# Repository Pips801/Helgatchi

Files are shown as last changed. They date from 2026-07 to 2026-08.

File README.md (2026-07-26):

# Helgatchi
Handheld BLE + WiFi Hunter

## What is it?
A portable, hand-held BLE beacon and WiFi AP scanner/hunter, with built-in alerting, 1.69” full-color screen, and external SMA-RP antenna all powered by the XIAO ESP32-S3. 

The Helgatchi will passively scan for BLE devices and WiFi SSIDs/APs, and alert when specific Manufacturers, naming schemes, or services are discovered. 

It can be configured to alert anything you want, such as:
- ALPR/Surveilance equipment
- Tactical equipment
- Cameras
- Hidden cameras
- Fitness wearables
- Audio/Video devices

You can create rules based on the following fields
| 🐑  	| MAC address 	| OUI (explicit) 	| OUI organization 	| MFG (explicit) 	| MFG organization 	| 802.11 SIG 	| Device name 	| SSID 	|
|---	|---	|---	|---	|---	|---	|---	|---	|---	|
| WiFi 	| ✅ 	| ✅ 	| ✅ 	| ❌ 	| ❌ 	| ✅ 	| ❌ 	| ✅  	|
| BLE  	| ✅ 	| ✅ 	| ✅ 	| ✅ 	| ✅ 	| ❌ 	| ✅ 	| ❌  	|

## Key Features
- Enclosed, portable, battery powered handheld rechargeable BLE and WiFi scanner and hunter that can live in your pocket.
- Passively scans for beacons in the background in-between sleeping - maximizing battery life. You can configure 
- Powered by the XIAO ESP32-S3
- 6 RGB LEDs
- 1.69" rounded screen
- Vibration motor for alerts
- You can change
  - Color scheme
  - Alert settings
    - Vibrate
    - LEDs
    - Screen Wake
  - Scan settings
    - Sleep duration
    - Scan duration
  - Rules for alerts
    - MAC address (BLE, WiFi)
    - Manufacturer (BLE, WiFi OUI)
    - Device name (BLE name, WiFi SSID)
    - Service (BLE)

## Specifications

| Spec | Info 	|
|---	|---	|
| MCU 	| XIAO ESP32-S3 	|
| Flash 	| 8MB 	|
| Battery  	| 400mAh - 1200mAh 3.7v LiPo 	|
| Screen 	| Waveshare 1.69” LCD - 240p × 280p 	|
| Antenna  	| XIAO -> u.FL > back PCB > SMA-RP > 2.4Ghz antenna 	|
| Size 	| Width: 50mm Length: 80mm 	|

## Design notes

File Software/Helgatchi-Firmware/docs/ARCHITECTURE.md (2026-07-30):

# Architecture

Quick map of the firmware. For per-phase implementation history see the
other docs in this directory; for current next-up work see `PHASE_6_SCAN_ENGINE.md`.

## Hardware

- **MCU**: ESP32-S3 (Seeed XIAO ESP32-S3 module)
- **Flash**: 8 MB
- **PSRAM**: 8 MB (LVGL framebuffers + LVGL allocator pool + scan ring + seen-devices map)
- **Display**: ST7789 SPI panel @ 80 MHz, 280×240 (no TE pin — frame tearing
  inherent above ~30 fps animation)
- **Radios**: BLE + WiFi (NimBLE for BLE, ESP32 WiFi for scan)
- **LEDs**: addressable WS2812 chain via FastLED
- **Motor**: PWM-driven haptic
- **Buttons**: left / right / center (debounced in `HalService`)
- **Battery**: VSENSE via ADC, USB-attach detect via SOF, charge-state inferred
- **Power**: deep-sleep wake via EXT1 on center button + RTC timer for scheduled scan windows; shipping mode for cold storage

## Build system

PlatformIO, Arduino-ESP32 framework. Three pre-scripts run before each
build (see `platformio.ini`):

1. `scripts/auto_montserrat.py` — scans source for referenced LVGL Montserrat
   font sizes and `-D`s them into the build.
2. `scripts/build_info.py` — emits `include/build_info.h` with build date and
   UI version (mtime of `Helgatchi UI.eez-project`).
3. `scripts/build_vendor_tables.py` — generates `include/vendor_tables_data.h`
   (~700 KB of flash data) from `scripts/vendor_sources/oui.csv.gz` and
   `scripts/vendor_sources/bt_companies.yaml`. Run
   `scripts/refresh_vendor_sources.py` manually to update the upstream cache.

Partition layout (`partitions.csv`): NVS 28 KB / factory 5 MB / spiffs ~3 MB
(LittleFS-formatted; partition subtype is `spiffs` because that's what
esptool/PIO look for, but the on-disk format is LittleFS via
`board_build.filesystem = littlefs`).

## Service model

Every subsystem is a `class FooService { void begin(EventBus&); void tick(); ... };`
with a single global instance (`extern FooService g_foo;`). `setup()` in
`main.cpp` initializes them in a specific order (some have prerequisites —
e.g. `g_rules` depends on `g_scan_service` and `g_alerts` being ready, and on LittleFS
being mounted).

Service catalog (`src/main.cpp` shows current init order):

| service | role |
|---|---|
| `g_bus` | Pub/sub event bus (queued; drained per main-loop tick) |
| `g_settings` | NVS-backed settings store (`SettingsKey` enum + `SKEY_*` macros) |
| `g_hal` | Display, LEDs, motor, buttons, ADC |
| `g_logger` | LVGL perf overlay gating, serial debug-level filtering |
| `g_console` | Serial command parser |
| `g_power` | Scan/sleep cycle, battery sampling, shipping mode |
| `g_alerts` | Active alert store (RTC slow memory persistence across deep sleep). Caps at 16 unacked — past that new detections are DROPPED, announced via `EV_ALERT_DROPPED` (throttled) so the UI can say so |
| `g_scan_service` | Scan-result ring buffer (256) + seen-devices map (128). Both in PSRAM |
| `g_rules` | Rules engine — loads `/rules/{factory,user}/*.json`, drains `g_scan_service`  |
| `g_leds` | LED pattern renderer (~30 fps), pattern name registry |
| `g_vibe` | Haptic step-machine, pattern name registry |
| `g_ui` | LVGL `lv_timer_handler` wrapper, render gating when screen off |
| `g_display` | Top-bar icon strings (battery / USB / BT / WiFi / bell) |
| `g_toast` | Transient self-dismissing messages on the LVGL top layer. No `begin()` — call `g_toast.show("…")` from any UI code |
| `g_settings_screen` | Settings widget wiring (EEZ-generated UI) |
| `g_alerts_screen` | Alert card UI (lives in its own file mirroring settings_service split)|

## Event bus

`include/event_ids.h` is the source of truth for event IDs. Two flavors:

- `CMD_*` — imperative requests (`CMD_SCAN_START`, `CMD_ALERT_ACK`, etc.)
- `EV_*` — immutable facts (`EV_ALERT_RAISED`, `EV_BATTERY_UPDATED`, etc.)

Payloads are an 8-byte tagged union (`include/event_payload.h`). Adding a new
event ID *to send a custom payload* means extending the union.

**Hot path note**: scan results do NOT go through the bus. `g_scan_service.publish()`
writes to a PSRAM ring buffer; `g_rules.tick()` drains it directly via
`g_scan_service.drain()`. Only the alert path that fires *after* matching emits bus
events (downstream of the hot loop).

## Storage tiers

| tier | what lives here |
|---|---|
| Flash (app) | Firmware, generated vendor tables, factory rule JSONs (via LittleFS image at build time) |
| NVS | Settings (`g_settings`), rule enable/disable overlay |
| RTC slow memory  | Active alerts (`g_alerts`) — survives deep sleep, cleared on cold boot |
| LittleFS | `/rules/factory/*.json` (read-only at runtime), `/rules/user/*.json` (writable) |
| PSRAM | LVGL framebuffers + LVGL allocator pool, scan ring + seen-devices map |
| Internal SRAM | Stack, FreeRTOS, hot in-flight data only |

## Conventions

- **Singular/plural serial verbs**: `setting`/`settings`, `alert`/`alerts`,
  `led`/`leds`, `rule`/`rules`. Singular mutates one thing; plural lists or
  manages many.
- **Underscore-as-space in serial values**: multi-word titles in `alert` and
  `rule create` use underscores (`title=Axon_device_nearby`). Other fields
  (vibe, led, type, action, etc.) take registry names verbatim.
- **Comma-separated arrays in rule criteria**: `rule add foo mfg=0x05D2,0x004C`
  adds two atomic criteria. `oui_org_contains` and `mfg_org_contains` expand
  at parse time into many atomic criteria by walking the vendor table.
- **Per-(rule, MAC) dedup**: alerts use identifier format
  `<rule_name>:<MAC_hex>` so re-firing on the same device updates last_seen
  rather than stacking new alerts.
- **Factory rule immutability**: `_rules[i].is_factory == true` blocks all
  content mutations. Only `enable`/`disable` works on factory rules, persisted
  via NVS overlay (survives FS reflash).

## Debugging / introspection commands

- `stats` — uptime, chip, memory, display fps, bus drops
- `scan` — list seen devices (dedup'd by MAC)
- `scan inject domain=... mac=... mfg=... name=...` — synthesize a scan
  result for testing the rules engine without real radio
- `vendor oui <AA:BB:CC>` / `vendor mfg <0xNNNN>` — forward lookup
- `vendor search <substr>` — list every IEEE org + BT SIG name containing the
  substring (same code path RulesService takes at rule load for `*_org_contains`)
- `rules` — list all rules with their full criteria (so `rule rm <name> <idx>`
  is unambiguous)
- `rules show <name>` / `rules stats` / `rules reload`
- `selftest` — GPIO short/load detection

## Things that have already burned us

- **DMA + PSRAM**: cache writeback needed before LovyanGFX flushes from PSRAM.
  See the `Cache_WriteBack_Addr` call in `ui_controller.cpp` flush_cb.
- **NimBLE timing**: not in the codebase yet (Phase 6), but historically
  `NimBLEDevice::init` on Arduino-ESP32 must come after WiFi init if both
  share radio coex.
- **LittleFS unlink while iterating**: the directory iterator holds FDs on
  entries — collect paths first, close the dir, then unlink.
- **Partition table changes** wipe NVS (and reformat LittleFS if the
  partition moves). Avoid changing offsets once stable.
- **ArduinoJson 7** allocates dynamically; on big rule files use stack-scoped
  `JsonDocument` to avoid leaks.

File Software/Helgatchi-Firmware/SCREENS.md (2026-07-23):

# Screens

This document describes the actual UI screens, their SquareLine Studio
implementation, and the wiring between SLS-exported widgets and firmware
behavior. The earlier revision was a design intent — this one tracks what
exists, what doesn't, and the conventions in use.

---

## Source of truth

- **SLS project** (external): `Helgatchi-UI`, SLS 1.6.0, targeting LVGL 9.3, "Arduino with TFT_eSPI" board template, "Force exported names to lower case" enabled, "Custom variable prefix" `uic`.
- **Exported files**: `src/UI/*.{c,h}` — *do not edit by hand, re-export overwrites.*
- **Firmware wiring**: `src/ui_controller.cpp`. All buttons / settings / battery / dim / haptic hooks live here.

Whenever the SLS project is re-exported, widget pointer names may change. The compiler will catch most of these as undeclared identifiers in `_bindings[]` / `_actions[]` / batteryLabels[] in `ui_controller.cpp`.

---

## Screens that exist today

| # | Screen | SLS object | Status |
|---|---|---|---|
| 1 | Splash | `ui_screen_splash_screen` | ✅ Implemented |
| 2 | Status | `ui_screen_status_screen` | ✅ Renders top bar, no body content yet |
| 3 | Menu | `ui_screen_menu_screen` | ✅ Horizontal carousel, only Settings panel exists |
| 4 | Settings | `ui_screen_settings_screen` | ✅ Most-developed screen — actual settings widgets bound to NVS |

Screens deferred to later milestones: **Scan, Devices, Device Detail, Rules, Alerts, About**. Each will follow the same pattern as Settings (top bar component + content panel + binding table).

---

## Top bar component

Built once in SLS as a Component, instanced on Status / Menu / Settings (purple in the Hierarchy panel — they share the same Component definition and update together if edited).

Three labels per instance, named consistently across screens:
- `top_bar_left_text` — left-side status indicator (currently shows "zzz" placeholder on Menu, free text per screen)
- `top_bar_center_text` — screen title
- `top_bar_right_text` — battery percentage

The right-text labels are tracked in `_batteryLabels[]` in `ui_controller.cpp`. On `EV_BATTERY_UPDATED` they all get rewritten with the formatted percentage / "CHRG" / "FULL" / "??". A cached `_last_batt_*` is also re-applied when a screen loads, so a freshly-loaded screen paints immediately instead of waiting up to 30 s for the next battery sample.

To add the top bar to a new screen: drop the Component instance in SLS → re-export → add the new screen's `top_bar_right_text_*` pointer to `_batteryLabels[]`.

---

## Splash → Status

The splash → status transition is **defined in SLS itself**, not in C:
- Trigger: `LV_EVENT_SCREEN_LOADED` on splash
- Action: `Change Screen` to Status with `FADE_OUT`, 500 ms, **3000 ms delay**

The C side just calls `ui_init()` (loads splash) and lets LVGL handle the rest. This is the canonical SLS pattern — when something can be a CLICKED-event-driven screen change, prefer doing it in SLS.

The 3 second delay needs `lv_tick_set_cb(_tick_cb)` to be registered (LVGL 9.x removed `LV_TICK_CUSTOM`, so without this the delay never elapses). `UIController::begin()` does this before `lv_display_create`.

---

## Menu screen

Horizontal scroll-snap carousel (`ui_menu_screen_container_container5`). Each child panel is one menu entry. Currently only `panel_settings_pannel` (sic — SLS-generated typo) exists, with `lv_image_settings_image`, label, and a `Clicked → Change Screen → Settings` event defined in SLS.

Keypad navigation: `_grp_menu` is populated by iterating the carousel container's children, so adding a new menu panel in SLS (Devices, Rules, Alerts, etc.) auto-shows up in the focus cycle without code changes. LVGL's group focus auto-scrolls the snap container.

Adding a new menu entry:
1. In SLS: copy the Settings panel inside `container_container5`, rename, give it its own `Clicked → Change Screen → <target>` event
2. Re-export
3. (No C change needed for the menu screen itself)
4. Build / register the target screen separately

---

## Settings screen

The most-developed screen — every other future screen will follow this pattern.

### Layout
A top bar + a vertical scrollable panel (`panel_panel2`) of section labels and option containers. Each option container has a label and one widget (switch/dropdown/slider/button).

### Bound settings (`_bindings[]` in `ui_controller.cpp`)

Each entry is `{ &ui_<widget>, SKEY_<X> }` — the polymorphic `_readWidget` / `_writeWidget` handles the widget type at runtime, so a switch, dropdown, slider, etc. all work via the same path.

Currently bound:
| Widget | SLS pointer | SettingsKey |
|---|---|---|
| Brightness dropdown | `ui_settings_screen_dropdown_brightness` | `SKEY_SCREEN_BRIGHTNESS` |
| Performance Mode dropdown | `ui_settings_screen_dropdown_performance_mode` | `SKEY_PERF_MODE` |
| Debug over Serial switch | `ui_settings_screen_switch_debug_over_serial` | `SKEY_DEBUG_SERIAL_ENABLED` |
| Debug Level dropdown | `ui_settings_screen_dropdown_debug_level` | `SKEY_DEBUG_LEVEL` |
| Sleep with Serial switch | `ui_settings_screen_switch_sleep_while_serial` | `SKEY_DEBUG_SLEEP_WITH_SERIAL` |
| Sleep with USB switch | `ui_settings_screen_switch_sleep_while_usb` | `SKEY_SLEEP_WHILE_USB` |

### Custom (non-1:1) bindings

Some widgets don't map directly to a single SKEY:
- **BLE / WiFi scanning switches** combine into `SKEY_SCAN_MODE` via bit-OR (BLE = bit 0, WiFi = bit 1). Custom `_onScanBitsChanged` rebuilds the combined value from both switch states on any change. `_refreshScanBits()` in the other direction.
- **Show debug options switch** (`show_debug_options_switch`, `SKEY_DEBUG_ENABLED`): gates the visibility of the debug rows (`debug_over_serial_container`, `debug_level_container`, `device_info_container`, `reset_device_container`, `restart_tutorial_container`) via `_applyDebugVisibility()`. Default off; switching OFF also resets the [DEBUG] keys to defaults (cascade in SettingsService), and the factory reset re-hides everything. Keypad nav skips the hidden rows automatically (lv_group ignores objects with a hidden ancestor).

### Action buttons

Sleep and reboot moved to the power menu screen (which also owns the sleep
countdown text via `EV_SLEEP_COUNTDOWN_UPDATED`). The remaining settings-screen
buttons live in the debug section:
| Button | Behavior |
|---|---|
| `reset_device_button` | C-wired: `g_power_menu_screen.beginAction(CMD_POWER_FACTORY_RESET)` — shows the Power Action screen ("Wiping device...", cancellable during the hold), then factory wipe (settings/rules/alerts/admin) + reboot; comes back up like a first boot. The wipe+shipping-sleep variant `CMD_POWER_SHIPPING_RESET` is serial-only (`power shipping`) for the assembly line. |
| `debug_screen_button` | EEZ-flow navigation to the Debug Info screen |
| `restart_tutorial_button` | EEZ-flow navigation to the tutorial |

### Dropdown options must match the enum
SLS stores dropdown options as a `\n`-separated string and saves the index. **The index is the value stored in NVS.** If your dropdown options aren't in enum order, you'll silently store wrong values — we've eaten this bug twice (extra "Off" leading the Debug Level dropdown, slider range 50..255 vs enum 0..3 for brightness).

Current required option strings:
- Brightness: `Min\nLow\nMedium\nHigh\nMax` (matches `ScreenBrightness` enum)
- Performance Mode: `Performance\nBalanced\nPower Saver` (matches `PerfMode` enum, missing DYNAMIC by intent)
- Debug Level: `Info\nHigh\nRender\nScan\nPerf\nTeleplot` (index = `DebugLevel` enum value, 1:1). Perf = human-readable telemetry, Teleplot = `>k:v` graphing stream.

---

## Keypad input contract

UIController converts physical button events into LVGL keys with these conventions:

| Action | Default (nav mode) | In edit mode | Dropdown open |
|---|---|---|---|
| LEFT | `LV_KEY_PREV` (prev focused widget) | `LV_KEY_LEFT` (decrement value) | `LV_KEY_UP` (prev option) |
| RIGHT | `LV_KEY_NEXT` (next focused widget) | `LV_KEY_RIGHT` (increment value) | `LV_KEY_DOWN` (next option) |
| CENTER short on Status | open Menu (direct screen change, bypasses LVGL) | — | — |
| CENTER short elsewhere | `LV_KEY_ENTER` | `LV_KEY_ENTER` (commit edit) | `LV_KEY_ENTER` (select option) |
| CENTER long | back to Status (panic-out) | — | — |

**Common mistakes**:
- Sending `LV_KEY_LEFT/RIGHT` for navigation. Switches interpret those as direct toggle and you'll never get past the first switch in the focus group.
- Forgetting that `lv_dropdown_is_open()` is widget-local state, not group editing state. `lv_group_get_editing()` returns false even with a dropdown list visible. Both checks needed.

### Group population
`_populateGroupFromSubtree()` recursively walks a screen's widget tree and adds anything `lv_obj_check_type` recognises as interactive (switch, checkbox, dropdown, roller, slider, arc, button) to the group **in DOM order**. So the focus cycle matches the order children appear in SLS's Hierarchy panel — drag widgets there to reorder navigation.

---

## Screen lifecycle hooks

`_scr_evt_cb` (registered for all four screens via `_registerScreenLogging`) handles three things on every screen transition:

1. **Logging** — `[t] SCREEN_LOAD_START / LOADED / UNLOAD_START / UNLOADED  <name>` to serial when debug serial is on.
2. **Group switching** — on `LV_EVENT_SCREEN_LOAD_START`, set the keypad indev's group to the screen's group (or NULL for splash/status).
3. **Settings refresh** — on Settings screen load, repaint widget values from `g_settings`.

Plus battery label re-paint (`_refreshBatteryLabels`) on every screen-load so the right-text shows the latest reading immediately.

---

## What's not implemented

- **Scan screen** — needs to surface scan state, lock-on, scan mode toggle. Future commands: `CMD_SCAN_START`, `CMD_SCAN_STOP`, `CMD_SCAN_LOCKON_START/STOP`. Will subscribe to `EV_SCAN_STATE_CHANGED` for the toggle status.
- **Devices screen** — paged list. Needs Entity Store + AppState before this is meaningful. Pagination + per-row rendering will be the main UI work.
- **Device Detail screen** — view one entity, optionally `CMD_RULE_ADD_CUSTOM` from it.
- **Rules screen** — toggle rule packs (`CMD_RULE_PACK_ENABLE/DISABLE`), wipe customs.
- **Alerts screen** — list active + history, ack (`CMD_ALERT_ACK`) / snooze (`CMD_ALERT_SNOOZE`).
- **About screen** — firmware version, build info, ruleset version.

The pattern for each is identical to Settings: SLS top-bar instance + content layout + add the appropriate widgets to either `_bindings[]` (state) or `_actions[]` (commands). Screen-load hook for any data that needs paint-on-entry.

---

## Cross-cutting

### `EV_UI_ACTIVITY` is used as the activity heartbeat
Every button press posts it. Every character typed in the serial console posts it. PowerManager updates `_last_activity_ms` and forces display ON. If a future input source (touch, gesture) is added, fire `EV_UI_ACTIVITY` from there too.

### Render is gated by display state
`UIController::tick()` is a no-op when `_render_enabled` is false. PowerManager flips it from `_setDisplay`: `OFF → false`, `ON/DIM → true`. This saves ~70 % CPU during silent TIMER-wake scan windows.

### LVGL FPS overlay
Compiled in via `LV_USE_PERF_MONITOR=1`, but visibility is runtime-toggled by `LogService::applyPerfMonitor()` based on `DebugLevel`. Reapplied on:
- After `g_ui.begin()` (display-create auto-shows the overlay; we have to actively re-hide if level < PERF)
- On every `EV_SETTINGS_CHANGED` that crosses the PERF threshold
- On `_setDisplay(ON/DIM)` (covers wake-from-silent-scan transitions)

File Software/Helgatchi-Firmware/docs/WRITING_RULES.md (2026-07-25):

# Writing rulesets

The authoritative guide to Helgatchi's rules engine: how rulesets and rules
work, every field, the pattern/regex language, worked examples, how to get a
ruleset onto the device, and how to test it. If you're creating or editing a
ruleset, this is the page to read.

**Terminology.** A **ruleset** is a single JSON file. It holds a collection of
**rules** plus the alert behaviour (title, LED, vibration, type, …) to use when
the ruleset fires. Each **rule** is one match entry — an object in the file's
`criteria` array. A ruleset fires when **any** of its rules matches a nearby
device; it then raises a single alert configured by that ruleset. Because
behaviour is per-ruleset, **don't duplicate the same rule across multiple
rulesets** — a device that matches two rulesets raises two alerts.

## Contents

1. [Quick reference](#1-quick-reference)
2. [How rulesets & rules work](#2-how-rulesets--rules-work)
3. [Ruleset anatomy — the top-level fields](#3-ruleset-anatomy--the-top-level-fields)
4. [Rules — the match entries](#4-rules--the-match-entries)
5. [Patterns & regex](#5-patterns--regex)
6. [Vendor-name matching](#6-vendor-name-matching)
7. [Worked examples](#7-worked-examples)
8. [A full annotated ruleset](#8-a-full-annotated-ruleset)
9. [Deploying rulesets](#9-deploying-rulesets)
10. [Console command reference](#10-console-command-reference)
11. [Testing & validating your ruleset](#11-testing--validating-your-ruleset)
12. [Migration note](#12-migration-note)
13. [Gotchas checklist](#13-gotchas-checklist)
14. [Internals (for engine contributors)](#14-internals-for-engine-contributors)

---

## 1. Quick reference

A ruleset is one JSON file. Minimal shape:

```json
{
  "name": "flock_safety",
  "title": "Flock nearby",
  "type": "ble",
  "criteria": [
    { "oui": ["B4:1E:52"] },
    { "name": [".*flock.*", ".*alpr.*"] }
  ]
}
```

**Ruleset fields** (top level)

| Field | Required | Value |
|---|---|---|
| `name` | yes | unique id, ≤ 55 chars. For **user** rulesets it is also the on-disk filename (`/rules/user/<name>.json`), so keep it path-safe — `[a-z0-9_]`. Factory rulesets are read-only (never written back) and may use display-style names, including spaces (e.g. `"Flock Safety"`). |
| `title` | no  | text on the alert card (defaults to `name`) |
| `type` | no  | `ble` \| `wifi` \| `sys` \| `batt` \| `auto` (default: infer) |
| `action` | no  | `alert` (default) \| `party` |
| `vibe` | no  | haptic pattern name (`vibe list` on the console) |
| `led` | no  | LED pattern name (`led list` on the console) |
| `tag` | yes | array of category tags (e.g. `["tactical", "camera"]`) |
| `criteria` | yes | the ruleset's rules — an array of match entries (below) |

**Rule fields** (each entry in `criteria`)

| Field | Matches | Value |
|---|---|---|
| `oui` | leading MAC bytes (24–48 bit) | `"B4:1E:52"`, `"70:B3:D5:1A:2"` |
| `mac` | full 6-byte MAC | `"12:34:56:78:9A:BC"` |
| `mfg` | BT SIG company id | `"0x05D2"` |
| `service` | advertised BLE service UUID | `"180F"`, `"0x180F"`, or full 128-bit |
| `name` | BLE name / Wi-Fi SSID | **pattern** |
| `ssid` | name, Wi-Fi only | **pattern** |
| `oui_org` | IEEE vendor name for the OUI | **pattern** (matched at runtime) |
| `mfg_org` | BT SIG company name | **pattern** (matched at runtime) |
| `ie_sig`  | Wi-Fi 802.11 IE fingerprint, Wi-Fi only | **pattern** (see below) |

`ie_sig` matches the ordered information-element fingerprint the WiFi sniffer
builds for each captured beacon / probe request: the IE tag numbers in order,
SSID (tag 0) omitted, joined by `;`, with vendor IEs (tag 221) expanded to
`221:<first up-to-8 payload bytes in lowercase hex>`. Example (a Flock camera's
station-mode probe request):
`2;12;127;221:506f9a16030103;45;191;221:0050f208000000`. Use `;` — not `,` —
between tags (comma is the criterion value separator). This fingerprint identifies
a device by *how* it probes, independent of its (often shared or randomized) MAC —
it's how the Flock ruleset tells a real camera from any other Espressif/Liteon
device. To capture one from a real device, enable WiFi scanning and read the `ie=`
field off the `scan` debug log (`debug level scan`).

**Pattern cheat sheet** (case-insensitive, matches the *whole* value)

| Intent | Pattern |
|---|---|
| equals | `flock` |
| contains | `.*flock.*` |
| starts with | `flock.*` |
| ends with | `.*cam` |
| regex | `BWL\d-\d*` (in JSON: `"BWL\\d-\\d*"`) |

---

## 2. How rulesets & rules work

The scan engine publishes every BLE/Wi-Fi sighting into a ring buffer. The rules
service drains that ring and tests each sighting against the rules of every
**enabled** ruleset. When any rule in a ruleset matches, the ruleset fires its
action (raise an alert, or start party mode) using its configured behaviour.

Rulesets load **disabled** — shipped factory rulesets and anything flashed later
arrive silent until the user enables them (rules screen, `rule enable <name>`,
or the upcoming tag bulk-toggles). The exception: rulesets deliberately created
on-device (`rule create` / `rule save`) start enabled. Enabled-state lives in an
NVS overlay, not in the ruleset files, so it survives an FS reflash; a factory
reset or full erase returns every ruleset to disabled.

- **Behaviour is per-ruleset.** `title`, `led`, `vibe`, `type` and `action` are
  set once on the ruleset and apply to whatever its rules match.
- **Within a ruleset, everything is OR.** Any one rule matching fires the
  ruleset, and any one value inside a rule counts as a hit. There is **no AND**
  across the rules of a ruleset today — every rule is OR'd.
- **Don't duplicate a rule across rulesets.** Each ruleset that matches a device
  fires independently, so overlapping match logic in two rulesets means two
  alerts for the same device. Put a given match in exactly one ruleset.
- **One fire per (ruleset, sighting).** Matching stops at the first rule that
  hits in a ruleset.
- **Dedup is per (ruleset, MAC).** A device that keeps advertising refreshes the
  ruleset's existing alert ("last seen") instead of stacking duplicates.
- **`type` categorises the alert; it does not gate matching.** A `name` rule is
  tested against both BLE names and Wi-Fi SSIDs. Only `ssid` is Wi-Fi-gated.
- **Factory beats user.** On a `name` collision the read-only factory ruleset
  wins.
- **Enable/disable is sticky.** Disabling a ruleset is stored in NVS and survives
  a reboot and even a filesystem reflash.

---

## 3. Ruleset anatomy — the top-level fields

These configure the ruleset's identity and the alert it raises.

### `name` (required)

The unique id and the filename (`<name>.json`). Lowercase letters, digits and
underscores only; ≤ 55 characters. Cannot be changed after creation via the
editor (it's the identity).

### `title`

The human string shown on the alert card. Defaults to `name`. May contain
spaces and punctuation. (Over the serial console an underscore becomes a
space — see §10.)

### `type`

The alert category, one of:

| Value | Meaning |
|---|---|
| `ble`  | Bluetooth device |
| `wifi` | Wi-Fi device |
| `sys`  | system alert |
| `batt` | battery alert |
| `auto` | infer from the sighting's radio (default if omitted) |

This only labels the resulting alert; it does **not** restrict which sightings
the ruleset can match.

### `action`

- `alert` (default) — raise/refresh an alert card with the ruleset's `title`,
  `vibe` and `led`.
- `party` — trigger party mode (rainbow LEDs, haptics, animation); no alert
  card. Used by `party.json`.

### `vibe` / `led`

Names of registered haptic / LED patterns. Omit for the service default. List
the available names on the console with `vibe list` and `led list`.

---

## 4. Rules — the match entries

`criteria` is the ruleset's list of rules. Each rule is a single-key object that
names one field and gives an array of values (the values within a rule are OR'd).
There are two kinds of field.

### Literal fields

| Field | Format | Notes |
|---|---|---|
| `oui` | `"B4:1E:52"`, `"8C:1F:64:F"`, `"70:B3:D5:1A:2"` | a leading MAC prefix, 24–48 bits: MA-L (3 octets), MA-M (28-bit / 7 nibbles), MA-S (36-bit / 9 nibbles), up to a full MAC. Colons optional; an odd trailing nibble is allowed. Use `mac` for an exact address. |
| `mac` | `"12:34:56:78:9A:BC"` | a single exact device |
| `mfg` | `"0x05D2"` | 16-bit BT SIG company id from the advert |
| `service` | `"180F"` / `"0x180F"` / `"0000180f-0000-1000-8000-00805f9b34fb"` | a service UUID advertised by the device; short forms are promoted onto the BLE base UUID |

### Pattern fields

| Field | Matched against | When |
|---|---|---|
| `name` | BLE adv name or Wi-Fi SSID | runtime, per sighting |
| `ssid` | the name, **only for Wi-Fi** sightings | runtime |
| `oui_org` | the IEEE vendor name of the sighting's OUI | resolved per sighting |
| `mfg_org` | the BT SIG company name of the mfg id | resolved per sighting |

`oui_org` / `mfg_org` resolve the sighting's vendor name at match time (one
cached vendor lookup per sighting) and test the pattern against it — there's no
vendor-table scan at load, so they don't slow boot. See §6.

---

## 5. Patterns & regex

### The key principle

> A pattern is **case-insensitive** and must match the **whole** value.

Full-match (anchored) is the thing people trip on: `flock` means the value *is
exactly* `flock`, not "contains flock". To match part of a value, add `.*`
wildcards yourself.

### The four everyday shapes

| Intent | Pattern | Matches | Does **not** match |
|---|---|---|---|
| equals | `flock` | `flock`, `FLOCK` | `flock-cam`, `myflock` |
| contains | `.*flock.*` | `Flock-Cam`, `myFLOCKing` | `flo`, `lock` |
| starts with | `flock.*` | `flock`, `flock-cam` | `myflock` |
| ends with | `.*cam` | `body-cam`, `CAM` | `camera` |

These cost nothing at runtime (they run as plain string compares — §14). Reach
for real regex only when a value has *structure* (a serial number, a suffix).

### Regex tokens

Patterns below are shown **as the matcher sees them**. In a JSON file every
backslash is doubled — `\d` is written `"\\d"` (see [JSON escaping](#writing-patterns-in-json)).

**`.` — any single character**

| Pattern | Matches | Not |
|---|---|-----|
| `a.c` | `abc`, `a5c`, `a-c` | `ac`, `abbc` |

**`* + ?` — repeat the preceding element** (zero-or-more, one-or-more, zero-or-one)

| Pattern | Matches | Not |
|---|---|-----|
| `ab*c` | `ac`, `abc`, `abbbc` | `abx` |
| `ab+c` | `abc`, `abbc` | `ac` |
| `colou?r` | `color`, `colour` | `colouur` |

**`\d \D` — digit / non-digit**

| Pattern  | Matches | Not |
|---|---|-----|
| `\d\d\d` | `192`, `007` | `19`, `1a2` |
| `cam\d+` | `cam1`, `cam42` | `cam`, `camx` |
| `\D` | `x`, `-` | `5` |

**`\w \W` — word `[A-Za-z0-9_]` / non-word**

| Pattern | Matches | Not |
|---|---|-----|
| `\w+` | `node_7`, `AB12` | `a-b`, `a b` |

**`\s \S` — whitespace / non-whitespace**

| Pattern | Matches | Not |
|---|---|-----|
| `ap\sname` | `ap name` | `apname` |

**`[...]` `[^...]` — character sets & ranges** (ranges fold case: `[a-z]` also matches `B`)

| Pattern | Matches | Not |
|---|---|-----|
| `[bc]at` | `bat`, `cat` | `hat` |
| `[0-9a-f]+` | `3f`, `a0b1` | `3g`, `xyz` |
| `[^_]+` | `abc` | `a_b` |

**`\` — escape a metacharacter to a literal** (`. * + ? [ ] ( ) { } | ^ $ \`)

| Pattern | Matches | Not |
|---|---|-----|
| `v\d\.\d` | `v3.1` | `v3x1`, `v31` |
| `10\.0\.0\.\d+` | `10.0.0.5` | `10x0x0x5` |
| `\*` | `*` | `x` |

**`^` `$` — anchors** — redundant (patterns are already fully anchored) but
tolerated. `^flock$` behaves exactly like `flock`.

### What's not supported (and what to do instead)

| Missing | Instead |
|---|---|
| alternation `a\|b` | use separate array values: `["a", "b"]` |
| bounded repeat `\d{2,4}` | spell it: `\d\d`, `\d\d\d?\d?`, or loosen to `\d+` |
| capture groups `(ab)+` | flatten the pattern |
| backreferences | not available |

Use **arrays** rather than clever single patterns — a single `name` rule can
carry several alternatives:

```json
{ "name": [".*flock.*", ".*alpr.*", "cam\\d+"] }
```

matches a name containing "flock", **or** "alpr", **or** the regex `cam\d+`.

### Writing patterns in JSON

JSON uses `\` for its own escapes, so a regex backslash must be **doubled**:

| Matcher sees | JSON file |
|---|---|
| `\d` | `"\\d"` |
| `\w+` | `"\\w+"` |
| `BWL\d-\d*`  | `"BWL\\d-\\d*"` |
| `v\.\d` | `"v\\.\\d"` |

A single `\d` in a file is invalid JSON — the whole file is rejected at load
with a parse error on the console. (The console `rule add` command is *not* JSON;
there you type a single backslash.)

### Limits

Patterns are capped at **64 characters**.

---

## 6. Vendor-name matching

`oui_org` and `mfg_org` match a **pattern against the vendor/company name** — so
you can flag a manufacturer without hand-listing their prefixes. At match time
the device's vendor name is looked up (from its OUI, or its BT SIG company id)
and your pattern is tested against it.

```json
{ "oui_org": [".*flock.*"] }       // fires when the OUI's IEEE vendor name contains "flock"
{ "mfg_org": [".*motorola.*"] }    // fires when the BT SIG company name contains "motorola"
{ "oui_org": ["sierra wireless"] } // exact vendor-name match (names are suffix-stripped)
```

Keep patterns reasonably specific — an overly broad one (`.*a.*`) will match a
huge range of vendors. Vendor names have corporate suffixes stripped
("Apple, Inc." → "Apple"), so match on the brand.

---

## 7. Worked examples

Each block below is a single rule you drop into a ruleset's `criteria` array.

**Regional serial scheme** (the WatchGuard case) — `BWL9-089912`, `BWL5-012241`:

```json
{ "name": ["BWL\\d-\\d*"] }
```

**Body cam labelled `AX` + exactly six digits** (no `{6}`, so spell it):

```json
{ "name": ["AX\\d\\d\\d\\d\\d\\d"] }
```

**Printer with a random hex suffix**, e.g. `HP-3f9a`:

```json
{ "name": ["hp-[0-9a-f]+"] }
```

**Access point on the 5 GHz band** whose SSID ends `_5G`:

```json
{ "ssid": [".*_5g"] }
```

**A device family by several keywords** (contains-any):

```json
{ "name": [".*dashcam.*", ".*bodycam.*", ".*evidence.*"] }
```

**A whole vendor, by name, without listing OUIs:**

```json
{ "oui_org": [".*axon.*"], "mfg_org": [".*axon.*"] }
```

**One exact device (allowlist/party target):**

```json
{ "mac": ["12:34:56:78:9A:BC"] }
```

**A longer OUI block** — an MA-M (28-bit) or MA-S (36-bit) assignment, more
specific than the shared 24-bit prefix it sits under:

```json
{ "oui": ["70:B3:D5:1A:2"] }
```

---

## 8. A full annotated ruleset

JSON has **no comments** — this block is annotated for learning only. A valid,
copy-pasteable version follows.

```jsonc
{
  "name": "acme_surveillance",   // ruleset id — [a-z0-9_], <= 55 chars, unique
  "title": "ACME gear nearby",   // text shown on the alert card
  "vibe": "double_tap",          // haptic pattern (omit for the default; `vibe list`)
  "led": "red_blue",             // LED pattern (omit for the default; `led list`)
  "type": "ble",                 // alert category: ble | wifi | sys | batt | auto
  "action": "alert",             // alert | party
  "criteria": [                  // the ruleset's rules — ANY one matching fires it (all OR'd)

    // --- literal rules ---
    { "oui": ["00:1D:96", "B4:1E:52"] },          // match either 24-bit MAC prefix
    { "mac": ["12:34:56:78:9A:BC"] },             // one exact device
    { "mfg": ["0x05D2", "0x0008"] },              // BT SIG company id(s)
    { "service": ["180F", "0x180A",               // advertised service UUID: short...
                  "0000fe2c-0000-1000-8000-00805f9b34fb"] }, // ...or full 128-bit

    // --- pattern rules (case-insensitive, whole-value) ---
    { "name": ["ACME.*",                          // name/SSID starts with "acme"
               ".*bodycam.*",                     // ...or contains "bodycam"
               "AX\\d\\d\\d\\d\\d\\d"] },          // ...or "AX" + exactly six digits
    { "ssid": [".*_5g", "ACME-[0-9]+"] },         // Wi-Fi ONLY: ends "_5g", or "ACME-"+digits
    { "oui_org": [".*acme.*"] },                  // any OUI whose vendor name contains acme
    { "mfg_org": [".*acme.*"] }                   // any BT SIG company containing acme
  ]
}
```

The same ruleset as a valid file (comments removed, backslashes doubled):

```json
{
  "name": "acme_surveillance",
  "title": "ACME gear nearby",
  "vibe": "double_tap",
  "led": "red_blue",
  "type": "ble",
  "action": "alert",
  "criteria": [
    { "oui": ["00:1D:96", "B4:1E:52"] },
    { "mac": ["12:34:56:78:9A:BC"] },
    { "mfg": ["0x05D2", "0x0008"] },
    { "service": ["180F", "0x180A", "0000fe2c-0000-1000-8000-00805f9b34fb"] },
    { "name": ["ACME.*", ".*bodycam.*", "AX\\d\\d\\d\\d\\d\\d"] },
    { "ssid": [".*_5g", "ACME-[0-9]+"] },
    { "oui_org": [".*acme.*"] },
    { "mfg_org": [".*acme.*"] }
  ]
}
```

---

## 9. Deploying rulesets

There are two homes for rulesets, with different install paths.

### Factory rulesets (shipped in the image)

Read-only seeds under `data/rules/factory/`. To add or change one:

1. Create/edit the `.json` file in `data/rules/factory/`.
2. Syntax-check it before flashing: `python -m json.tool data/rules/factory/your_ruleset.json`
   (prints the file if valid, or points at the first syntax error). Full
   behavioural testing comes after flashing — see §11.
3. Build and flash the filesystem image:
   ```
   pio run -t buildfs      # build the LittleFS image from data/
   pio run -t uploadfs     # flash it
   ```

Factory rulesets can't be edited on-device; the firmware never rewrites them.

### User rulesets (created at runtime)

Writable, stored under `/rules/user/`, auto-persisted on every change and kept
across a firmware-only reflash. Create them either way:

- **WebFlasher** — connect, open the rules card, add a ruleset with the field +
  match-mode dropdowns, Save. It sends `rule save <json>` for you.
- **Serial console** — `rule save <json>` for a whole ruleset, or build one up
  with `rule create <name>` then `rule add <name> <field>=<values>` (§10).

A user ruleset with the same `name` as a factory ruleset is ignored (factory
wins).

### Lifecycle

- `rule reload` — wipe in-memory rulesets and re-read both directories (also
  zeroes match counters).
- `rule enable <name>` / `rule disable <name>` — sticky, stored in NVS.
- `rule delete <name>` — removes a **user** ruleset and its file.
- `pio run -t erase` — nuke everything (NVS + filesystem). Only needed to escape
  stale state; not part of normal ruleset work.

---

## 10. Console command reference

The `rule` commands manage **rulesets** (the command name predates the
ruleset/rule split); `rule add` and `rule rm` add and remove individual rules
inside a ruleset.

```
rule                          show this help
rule list                     list every ruleset with its rules
rule show <name>              ruleset details + live match count
rule create <name> [k=v ...]  new user ruleset (k=v: title= vibe= led= type= action=)
rule add <name> <f>=<v>[,<v>] add one or more rules to a ruleset (space-separated)
rule rm <name> <idx>          remove the Nth rule from a ruleset
rule delete <name>            delete a user ruleset
rule enable  <name>           enable  a ruleset (NVS overlay)
rule disable <name>           disable a ruleset (NVS overlay)
rule reload                   re-read /rules/{factory,user}; zero counters
rule stats                    match / ring-drain counters
rule dump                     all rulesets as one JSON line (used by the WebFlasher)
rule save <json>              create/replace a user ruleset from a JSON object
```

Support commands:

```
led list                      list LED pattern names for `led`
vibe list                     list haptic pattern names for `vibe`
scan inject <k=v>             push a synthetic sighting (test the match path)
scan list                     show the seen-devices map
scan clear                    wipe the seen map
```

**Console input rules** (they differ from JSON):

- `_` becomes a space in string values, so `rule add r oui_org=sierra_wireless`
  matches "Sierra Wireless". A literal underscore can't be typed — use `\w` or
  author via JSON.
- No spaces or commas *inside* a value (they separate tokens / values).
- Backslashes are single here (`name=BWL\d-\d*`), doubled in JSON files.

Example, building a ruleset by hand:

```
rule create bwl_cams type=ble title=BWL_camera
rule add   bwl_cams name=BWL\d-\d*
rule add   bwl_cams oui_org=watchguard
rule show  bwl_cams
```

---

## 11. Testing & validating your ruleset

You don't need the real target device present to test a ruleset. The console can
inject synthetic sightings and report whether the ruleset fired. Run these in the
serial console or the WebFlasher's console view.

The goal is two checks: your ruleset **loads clean**, and it **fires on what you
intend — and nothing else**.

### Step 1 — Confirm it loaded

- **Saved via WebFlasher / `rule save`:** a bad ruleset is rejected on the spot
  (the editor shows an error; `rule save` prints `{"ok":false}`). Fix and resave.
- **Flashed as a factory file:** watch the boot log. You want
  `[rules] loaded N rules` (that count is rulesets). A malformed file logs a
  parse error naming the file; an unknown/removed field logs `bad criterion
  field`. Fix and reflash.
- Either way, run `rule show <name>` and read its rules back. Patterns print as
  `name ~ "..."`. **If a rule you wrote is missing, it was rejected** — usually
  an invalid pattern or a typo'd field name.

### Step 2 — Zero the counters

```
rule reload
```

This re-reads both directories and resets every ruleset's match counter to 0, so
you can measure from a clean slate. `rule show <name>` now reports `matches: 0`.

### Step 3 — Inject a device that SHOULD match

`scan inject` pushes a fake sighting through the real engine:

```
scan inject domain=bt mac=B4:1E:52:00:00:01 name=Flock-Cam
rule show flock_safety        # expect: matches: 1
```

Two constraints on injected sightings: the `name=` value **cannot contain
spaces**, and avoid `mac=AA:BB:CC:DD:EE:FF` (it triggers the factory party
ruleset). Set the fields your rules key on — `mac`/`oui` via `mac=`, `mfg` via
`mfg=`, `name`/`ssid` via `name=`, and `oui_org`/`mfg_org` by injecting a MAC
whose vendor your pattern matches.

### Step 4 — Inject a device that should NOT match

Just as important: prove the ruleset isn't too broad.

```
scan inject domain=bt mac=12:34:56:78:9A:B0 name=unrelated
rule show flock_safety        # expect: matches: 1  (unchanged)
```

This is where anchoring bugs show up. If you wrote `flock` (equals) but expected
"contains", a name like `Flock-Cam` won't match; if you wrote `.*a.*` you'll see
it match nearly everything.

### Step 5 — See the alert fire (optional)

`scan inject` a matching device, then check the device's alert screen (or the
`alerts` console command) for a card with your `title`, `vibe` and `led`.

### Step 6 — Clean up

```
rule delete <scratch_ruleset>   # remove any throwaway rulesets you created
scan clear                      # wipe the injected sightings
```

### Worked example — validating a regex rule end to end

```
rule reload
rule create wgtest
rule add wgtest name=BWL\d-\d*
rule show wgtest                                   # the rule prints: name ~ "BWL\d-\d*"
scan inject domain=bt mac=12:34:56:78:9A:C0 name=BWL9-089912
rule show wgtest                                   # matches: 1
scan inject domain=bt mac=12:34:56:78:9A:C1 name=BWLx-1
rule show wgtest                                   # matches: 1  (no change — \d needs a digit)
scan inject domain=bt mac=12:34:56:78:9A:C2 name=xBWL9-1
rule show wgtest                                   # matches: 1  (no change — anchored)
rule delete wgtest
scan clear
```

### When it doesn't behave

| Symptom | Likely cause |
|---|---|
| Ruleset missing from `rule list` | JSON parse error at load (check the boot log), or its `name` collides with a factory ruleset (factory wins) |
| A rule missing from `rule show` | invalid pattern or unknown field — that rule was rejected while the rest of the ruleset loaded |
| Never matches | bare literal used where you meant contains (add `.*…*`); or `ssid` used for a BLE device; or wrong field |
| Matches far too much | pattern too broad (e.g. `.*a.*`), or an `oui_org`/`mfg_org` pattern that expanded to a huge vendor set |
| Two alerts for one device | the same match lives in two rulesets — consolidate it into one |
| `rule add … name=…` returns `ERR` | the pattern failed validation (e.g. a leading `*`, an unterminated `[`, a trailing `\`) |

---

## 12. Migration note

The pre-regex rule fields are **removed**:

`name_equals`, `name_contains`, `ssid_equals`, `ssid_contains`,
`oui_org_equals`, `oui_org_contains`, `mfg_org_equals`, `mfg_org_contains`.

Migrate a `_contains` value to `.*value.*` and an `_equals` value to `value`.
Old field names in a stale user file are rejected at load with a
`[rules] ... bad criterion field` log line; the rest of the ruleset still loads.
Re-author the file or reflash the filesystem image. All factory rulesets already
use the new fields.

---

## 13. Gotchas checklist

- Bare literal = **equals**, not contains. Add `.*…*` for substring.
- Double backslashes in JSON (`"\\d"`); single on the console (`\d`).
- No `|` / `{m,n}` / groups — use array values or spell repeats out.
- No literal spaces or commas in console values; `_` → space on the console.
- `type` categorises the alert; it doesn't gate matching. `ssid` is Wi-Fi-only.
- Patterns ≤ 64 chars; keep `oui_org`/`mfg_org` reasonably specific (a broad one matches many vendors).
- Don't repeat a match across rulesets — you'll get one alert per matching ruleset.
- Factory rulesets are read-only on-device; edit the file and reflash the FS.

---

## 14. Internals (for engine contributors)

- **Storage.** Rulesets live in PSRAM (`RulesService`, `src/rules_service.cpp`).
  In the code a ruleset is a `Rule` and a rule is a `Criterion`; the caps are
  `MAX_RULES = 64` (rulesets) and `MAX_CRITERIA = 256` (rules per ruleset). The
  pattern kinds (`name`/`ssid`/`oui_org`/`mfg_org`) store a verbatim string plus
  a classified shape. `oui_org`/`mfg_org` are resolved at match time against the
  sighting's vendor name (one cached bsearch per sighting), not expanded at load.
- **Pattern classification.** Each pattern is classified once (`_classifyPattern`)
  into `PAT_EXACT` / `PAT_CONTAINS` / `PAT_PREFIX` / `PAT_SUFFIX` (plain
  case-insensitive string compares) or `PAT_REGEX`. Every shipped factory pattern
  is a fast-path shape, so the regex engine rarely runs and a busy area stays
  under ~1% CPU.
- **Regex engine.** `lib/re_lite/` — a small case-insensitive, full-match matcher
  (`. * + ? \d \w \s [ranges]`, anchors). Purpose-built, not a vendored library.
  Recursion/backtracking is bounded by the 64-char pattern cap.
- **Persistence.** User rulesets serialize to `/rules/user/<name>.json` on
  mutation; enabled-state is a single NVS blob listing the *enabled* ruleset
  names (rulesets load disabled — an absent blob means nothing is enabled), and
  survives an FS reflash.
- **Round-trip.** Pattern strings — including `oui_org`/`mfg_org` — are stored
  and re-serialized verbatim, so save/dump/reload preserve exactly what was
  written. (Before match-time resolution, `oui_org`/`mfg_org` used to persist as
  their expanded `oui`/`mfg` lists; they now round-trip as the pattern.)

> **Naming note.** The code, the serial `rule` commands, the JSON `criteria` key
> and the `/rules/` directories predate the ruleset/rule vocabulary and still say
> "rule" for the file. This doc uses ruleset (file) / rule (match entry); the API
> names are unchanged.

## 15. Roadmap — rules-engine v2

The engine is evolving under a locked v2 design. **Shipped so far:**

- **Regex + pattern fields** — `lib/re_lite/`, the `name`/`ssid`/`oui_org`/`mfg_org`
  pattern kinds and their fast-path shapes (§14).
- **Variable-length OUI prefixes** — 24/28/36/48-bit (MA-L / MA-M / MA-S / full
  MAC), nibble-wise (§1, `oui`).
- **Match-time vendor resolution** for `oui_org` / `mfg_org`.
- **Wi-Fi IE fingerprint** matching (`ie_sig`, §1) for probe / beacon frames.

**Not yet built:**

- **AND groups.** Every rule in a ruleset is OR'd (§2); there is no way to require
  "OUI X *and* SSID Y" as one condition. No workaround today.
- **Cross-ruleset alert de-duplication (rule priority)** — see below.

### 15.1 Cross-ruleset double-alerting (planned: rule priority / suppression)

**Problem.** Alert dedup is keyed on `<ruleset-name>:<MAC>` (built in
`RulesService::_fire`, `src/rules_service.cpp`), so it only coalesces re-fires
*within a single ruleset*. When two **different** rulesets match the same device,
each raises its own alert card. `_matchScan` evaluates every enabled ruleset
independently (first matching criterion fires that ruleset, then `break`), so
there is no cross-ruleset arbitration.

This is most visible for Flock. A Flock camera's probe request matches
`flock_safety.json` via `ie_sig` **and** `liteon_tech.json` (or
`motorola_solutions.json`) via the camera's module-vendor OUI — two or three cards
for one physical device. Those supplier-OUI rulesets are also inherently broad:
Liteon/Motorola OUIs (and `mfg 0x0008`) fire on *any* Liteon/Motorola gear, not
just Flock, and they carry the same `Tactical`/`Camera` tags as `flock_safety`, so
a tag bulk-enable switches all of them on together.

**Planned v2 fix.** Add a per-ruleset confidence/priority field. During the
`_matchScan` drain, once a high-confidence ruleset (e.g. one matching on `ie_sig`)
fires for a MAC, suppress lower-confidence OUI-only rulesets for that same MAC
within the batch. This keeps broad OUI rules as a genuine fallback — they fire
only when the precise rule doesn't — without the duplicate card.

**Interim mitigations (data-only, no code change):**

- **Retire / disable** the `(Flock) Liteon` and `(Flock) Motorola` supplier
  rulesets. `ie_sig` plus Flock's own registered OUI `B4:1E:52` (already in
  `flock_safety.json`) cover Flock cleanly; the supplier OUIs add mostly noise.
- **Or de-scope them:** rename to plain vendor rulesets and drop the
  `Tactical`/`Camera` tags, so a bulk-enable can't turn them on alongside
  `flock_safety`.

**Heavier alternative (not planned).** Re-key dedup to one card per **MAC**,
listing every ruleset that matched. This removes all cross-ruleset duplication
structurally, but reworks the alert model and the existing per-(rule, MAC) +
RTC-persistence dedup, so it is out of scope for v2.

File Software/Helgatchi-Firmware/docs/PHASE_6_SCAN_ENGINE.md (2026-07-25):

# Phase 6 — Scan engine

Goal: produce real BLE + WiFi scan results into the existing `ScanService`
ring so `RulesService` can fire on them. Everything downstream is already
plumbed and tested via `scan inject` — Phase 6 just replaces the synthetic
producer with real radios.

## Interface contract (do not change)

```cpp
// include/scan_service.h — the only producer entry point
void ScanService::publish(const ScanResult& r);
```

```cpp
// include/scan_types.h — what to fill in
struct ScanResult {
    uint8_t  domain;                // SCAN_BLE or SCAN_WIFI
    uint8_t  mac[6];
    int8_t   rssi;
    char     name[32];              // BLE adv name OR WiFi SSID, NUL-terminated, truncated
    uint16_t mfg_id;                // BT SIG company ID (BLE); 0 = none. Unused for WiFi.
    uint8_t  service_count;
    uint8_t  service_uuids[4][16];  // 128-bit, BLE wire order (LSB first); promote 16/32-bit via base UUID at publish time
    uint32_t timestamp_ms;          // millis() at the scan callback
};
```

Validation path: `scan inject domain=... mac=... ...` builds the same struct
and pushes it through the same ring. If your real-radio output matches what
`scan inject` produces for the same device, you're good.

## What already exists

- **Ring + seen map**: `ScanService` (PSRAM-backed). `publish()` is thread-
  safe-enough for the main loop (no locking yet — see "concurrency" below).
- **RulesService consumer**: drains the ring on every `tick()` via
  `g_scan_service.drain(&_ring_read_pos, ...)`. Match → alert.
- **Vendor resolution**: `vendor_lookup.h` exposes `vendor_oui_lookup(prefix)`,
  `vendor_mfg_lookup(id)`. Already used by `scan` list and rule pretty-print.
  Scan engine does NOT need to resolve names — just fill in raw MAC + mfg_id
  and downstream code does the rest.
- **PowerManager scan window orchestration**: exists, drives the wake / scan /
  sleep cycle. Today nothing emits `CMD_SCAN_START` / `CMD_SCAN_STOP` because
  there's no real scanner; PowerManager just toggles the timer cadence. When
  Phase 6 lands, those commands become live triggers.

## Settings the engine must honor

All in `include/settings_keys.h`:

| key | semantics |
|---|---|
| `SKEY_SCAN_MODE` | bitmask: bit 0 = BLE, bit 1 = WiFi. 0 = disabled (idle) |
| `SKEY_SCAN_DURATION_S` | how long a scan window lasts before PowerManager stops it |
| `SKEY_BLE_SCAN_WINDOW_MS` | NimBLE `setWindow()` parameter |
| `SKEY_BLE_SCAN_INTERVAL_MS`| NimBLE `setInterval()` parameter |
| `SKEY_WIFI_DWELL_MS` | per-channel dwell during WiFi scan |
| `SKEY_WIFI_HOP_INTERVAL_MS`| time between WiFi channel hops |
| `SKEY_PERF_MODE` | perf-vs-battery hint; engine can pick scan defaults from it |

Subscribe to `EV_SETTINGS_CHANGED` with mask `SMASK_SCAN` to re-apply on the
fly (or just on next scan start — whichever is simpler).

## Existing reserved event IDs to use

In `include/event_ids.h`:

- `CMD_SCAN_START` — PowerManager posts this when a scan window opens
- `CMD_SCAN_STOP`  — PowerManager posts this to end a window
- `CMD_SCAN_LOCKON_START` / `CMD_SCAN_LOCKON_STOP` — future "focus on one
  device" mode (Phase 7+); leave unhandled for now
- `EV_SCAN_STATE_CHANGED` — emit with payload
  `ScanStatePayload { uint8_t domain; uint8_t active }` on every radio
  start/stop. `domain` is `ScanDomain` (`SCAN_BLE` / `SCAN_WIFI`), `active` is
  0/1. ScanEngine emits this for BLE today (`_emitScanState`); WiFi will emit
  the same event with `SCAN_WIFI` once its radio path lands. The top-bar icons
  already consume it (DisplayService) to color the BT/WiFi glyphs per domain.

The existing `EV_OBS_*` and `EV_ENTITY_*` reservations are vestigial from
an earlier design pass. Don't use them; we may delete them in cleanup.

## Implementation outline

New files:
- `include/scan_engine.h`
- `src/scan_engine.cpp`

Skeleton:

```cpp
class ScanEngine : public IEventHandler {
public:
    void begin(EventBus& bus);
    void tick();                          // poll WiFi async results; BLE is callback-driven
    void onEvent(const Event& e) override;
private:
    EventBus* _bus = nullptr;
    bool      _ble_running  = false;
    bool      _wifi_running = false;
    uint32_t  _last_state_emit_ms = 0;

    void _startBle();
    void _stopBle();
    void _startWifi();
    void _stopWifi();
    void _applyMode(uint32_t mode_bitmask);
    void _onBleAdv(/* NimBLE callback args */);    // formats + publishes
    void _onWifiScanDone();                         // walks WiFi.SSID(i) etc.
};
extern ScanEngine g_scan_engine;
```

Wiring in `main.cpp`: `g_scan_engine.begin(g_bus);` AFTER `g_scan_service.begin()` and
`g_power.begin()` (so subscriptions land in the right order). Tick goes in
`loop()`.

### BLE (NimBLE)

Add `h2zero/NimBLE-Arduino` to `lib_deps`. Use passive scanning — less power,
no responses needed, doesn't betray our presence.

```cpp
NimBLEScan* scan = NimBLEDevice::getScan();
scan->setActiveScan(false);
scan->setInterval(g_settings.get(SKEY_BLE_SCAN_INTERVAL_MS));
scan->setWindow  (g_settings.get(SKEY_BLE_SCAN_WINDOW_MS));
scan->setCallbacks(this, /* wantDuplicates */ true);
scan->start(0, /* is_continue */ false);  // 0 duration = until stop()
```

In the callback, build `ScanResult`:
- `domain = SCAN_BLE`
- `mac` from `device.getAddress().getNative()` (note byte order — NimBLE
  returns big-endian; we want the MAC in display order, so check)
- `rssi = device.getRSSI()`
- `name` from `device.getName()` (truncate to 31 chars + null)
- `mfg_id` from `device.getManufacturerData()[0..1]` (LE) if mfg data present
- `service_uuids[]` from `device.getServiceUUIDCount()` / `device.getServiceUUID(i)`,
  promoted to 128-bit BLE wire order. **Don't publish > 4 UUIDs** — the
  `service_uuids` array is fixed at 4.
- `timestamp_ms = millis()`

Then `g_scan_service.publish(r)`.

### WiFi — promiscuous MGMT sniffer (not `WiFi.scanNetworks`)

WiFi discovery is a **promiscuous management-frame sniffer**, not an AP scan.
`WiFi.scanNetworks()` only enumerates access points (from their beacons / probe
responses), so a probe-requesting **station** — e.g. a Flock camera which (as of
~Dec 2025) runs in STA mode and only sprays wildcard probe requests — is
completely invisible to it. `scanNetworks` was also unstable on this S3+PSRAM
build (back-to-back `esp_wifi_scan_start` faulted). The sniffer is the same
mechanism the lock-on path uses reliably.

`ScanEngine::_startWifi()` puts the radio in promiscuous mode with a MGMT-only
filter and installs `wifiSniffRxCb` (on the WiFi task). That callback:

- accepts management frames (`type == 0`) of subtype 8 (beacon → `FRAME_BEACON`)
  or subtype 4 (probe request → `FRAME_PROBE_REQ`);
- takes `addr2` (transmitter) as the MAC, RSSI + current hop channel from
  `rx_ctrl`;
- walks the information elements (TLV, bounds-checked; `sig_len` includes the
  4-byte FCS tail, stripped before the walk) to extract the SSID (tag 0 → `name`,
  empty ⇒ wildcard) and build the IE fingerprint into `ScanResult::ie_sig`
  (tag order, SSID skipped, vendor tag 221 → `221:<≤8 bytes hex>`, `;`-joined);
- marshals the `ScanResult` through the same FreeRTOS queue the BLE path uses, so
  `publish()` stays single-threaded (drained in `tick()`).

`tick()` (via `_pollWifiSniff()`) hops the channel across `{1, 6, 11}` at
`WIFI_HOP_DWELL_MS` (300 ms). The `ie_sig` string feeds the `CRIT_IE_SIG` rule
criterion — see `docs/WRITING_RULES.md` and `data/rules/factory/flock_safety.json`
for the Flock fingerprint. Because the sniffer is passive (listen-only),
`SKEY_SCAN_ACTIVE` does not apply to WiFi.

### Concurrency

NimBLE callbacks fire on the BLE host task (separate from `loop()`). `publish()`
is currently not thread-safe — it writes `_write_pos` and the ring entry
without locking. For Phase 6, options:

1. **Easiest, do this first**: have the NimBLE callback enqueue minimal data
   into a FreeRTOS queue, drain it on `tick()` and publish from the main
   thread. Single-threaded publisher → no lock needed.
2. Make `ScanService::publish()` use `portMUX`/`taskENTER_CRITICAL` to serialize.

Pick (1) — keeps `ScanService` clean and is the standard ESP32 pattern.

## Test plan

**Bench**:
1. Build, flash, confirm `scan inject` still works (sanity).
2. Create a rule that matches a known nearby device (e.g. `rule create apple
   oui_org_contains=apple` — should match any AirTag/iPhone OUI).
3. Power on, walk around with an iPhone. `scan` should list iPhones with
   `Apple` in the vendor column. `alerts` should fire the rule.
4. Verify settings honored: change `SCAN_MODE` to BLE-only (1), reboot, verify
   WiFi entries don't appear.

**Edge cases to verify**:
- BLE flood (lots of advertisements/sec) doesn't overrun ring — check
  `rules stats` for `lost: N scan results dropped`.
- WiFi scan with no networks → empty result list, no crash.
- Both radios enabled simultaneously → no coex issues (NimBLE + WiFi share
  the radio, ESP32 handles arbitration but timing tightens).
- Power cycle during a scan window → next boot resumes cleanly.

## Out of scope for Phase 6

- "Lockon" mode (track one device, ignore everything else) — Phase 7+
- Mesh-bridge events (`EV_MESH_RULE_FIRED_RX`) — future networking work
- Device list screen on the UI — UI work, Phase 8+
- Scan-result enrichment beyond what `vendor_lookup` already does

## Quick links

- Producer interface: `include/scan_service.h`
- ScanResult struct: `include/scan_types.h`
- Existing test-injection path: `_cmdScan` in `src/serial_console.cpp`
  (`scan inject`)
- Rules consumer: `src/rules_service.cpp` (`tick()` → `_matchScan()`)
- Settings keys: `include/settings_keys.h`
- Existing power orchestration: `src/power_manager.cpp`

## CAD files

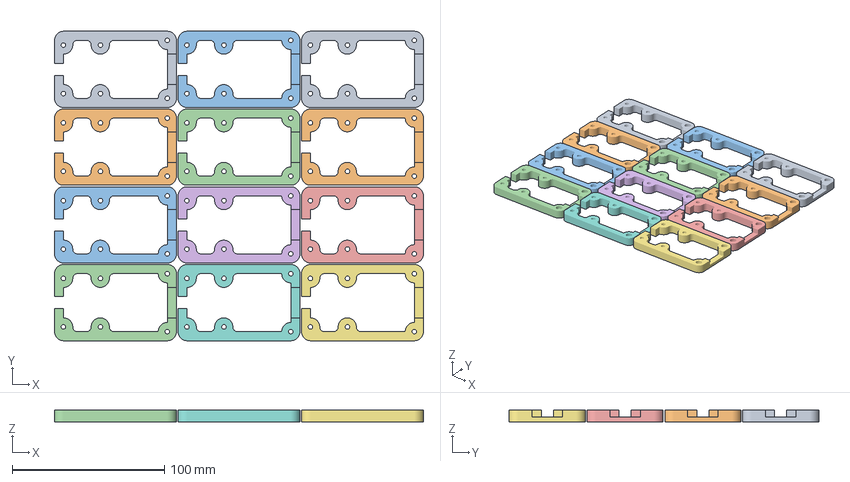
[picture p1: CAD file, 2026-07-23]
Hardware/Helgatchi Spacer/Conjoined Spacer 3x4.3mf
242.7 x 203.6 x 7.62 mm
Spacer-Body.step
Spacer-Body.step 1
Spacer-Body.step 2
Spacer-Body.step 3
Spacer-Body.step 4
Spacer-Body.step 5
Spacer-Body.step 6
Spacer-Body.step 7
Spacer-Body.step 8
Spacer-Body.step 9
Spacer-Body.step 10
Spacer-Body.step 11

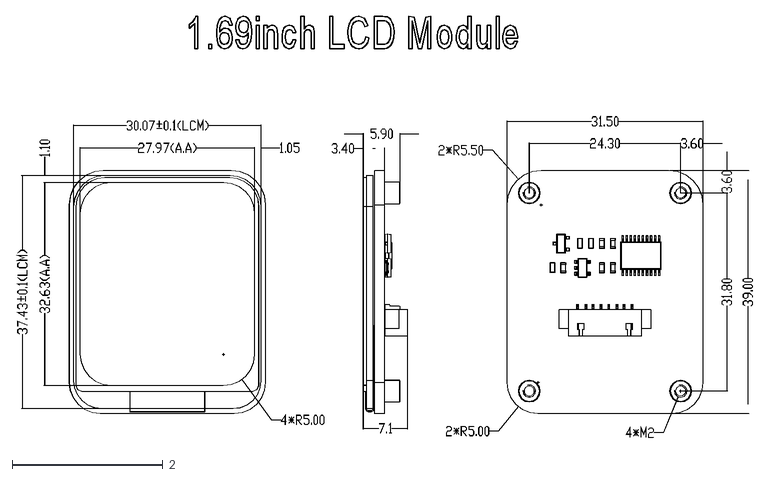
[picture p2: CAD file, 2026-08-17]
Hardware/PCB Components/1.69 inch LCD/1.69inch_LCD_Module_2Ddrawing.dxf
9.76 x 5.58

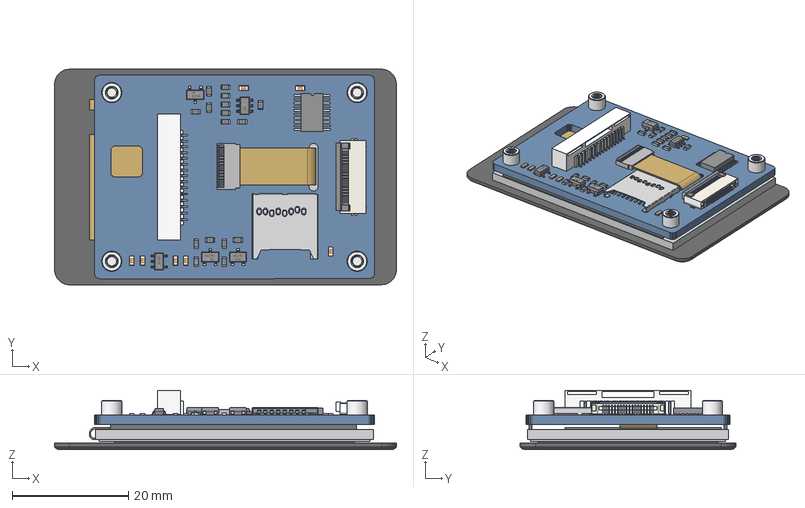
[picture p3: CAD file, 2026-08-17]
Hardware/PCB Components/2.0 inch touch LCD/2inch Capacitive Touch LCD.step
58.8 x 37.1 x 10.2 mm
User_Library-0603_SMD_Capacitor x 7
PITCH1MM-12PIN-SMT-HORIZONTAL
FPC0_5_2H-W__1_2_30012 x 18
SOT-23 x 3
_2_1_2_3_4_AF0 x 16
_7_1_2_AF0 x 16
SOT23-5AND6__100 x 6
SOT23-6-7933_AF0
Extruded
Extruded_1 x 20
SOT23-5AND6_00 x 5
SOT23-5-14065_AF0
FPC0_5_2H-W__1_2_30012_1 x 18
2inch Capacitive Touch LCD_LCD
2inch Capacitive Touch视窗
SMTSO-M2-2_5ET x 4

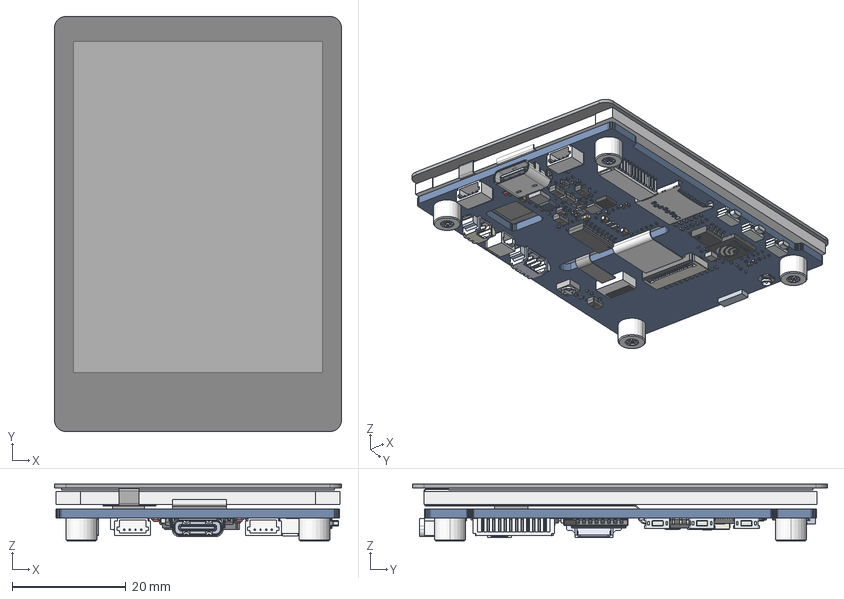
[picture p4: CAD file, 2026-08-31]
Hardware/PCB Components/2.8 inch touch LCD/esp32-s3-touch-lcd-2_8.stp
50.5 x 73.1 x 10.0 mm
2_8INCH-240X320-TP
2_8INCH-240X320-LCD
BOARD
5_1_2_A x 26
_7_AF0 x 26
SOIC16-150
USER_LIBRARY-RES_0603-0201_1 x 27
USER_LIBRARY-RES_0603-0201_2 x 27
USER_LIBRARY-RES_0603-0201_3 x 27
USER_LIBRARY-RES_0603-0201_4 x 27
3_1_A x 12
2_A x 30
3_1_2_A x 4
SOT-23 x 4
USER_LIBRARY-LED_0603_R_-188871 x 2
USER_LIBRARY-LED_0603_R_PAD004 x 2
USER_LIBRARY-LED_0603_R_FILLET x 2
USER_LIBRARY-LED_0603_R_-191226 x 2
USER_LIBRARY-LED_0603_R_PAD x 2
SOD323 x 4
USER_LIBRARY-U_FL-R-SMT_10_
EXTRUDED-396686
FPC0_5_2H-W__1_2_30012 x 18
EXTRUDED-456320
EXTRUDED-456692
EXTRUDED-506174
USER_LIBRARY-SOIC-8-150_PIN_SOI x 8
USER_LIBRARY-SOIC-8-150_SOIC_15
EXTRUDED-511087
SOT23-5AND6_00 x 5
SOT23-5-14065_AF0
USER_LIBRARY-ESP32-S3-SOC_1
USER_LIBRARY-ESP32-S3-SOC_2
USER_LIBRARY-ESP32-S3-SOC_3
USER_LIBRARY-ESP32-S3-SOC_4
USER_LIBRARY-ESP32-S3-SOC_5
USER_LIBRARY-ESP32-S3-SOC_6
USER_LIBRARY-ESP32-S3-SOC_7
USER_LIBRARY-ESP32-S3-SOC_8
USER_LIBRARY-ESP32-S3-SOC_9
USER_LIBRARY-ESP32-S3-SOC_10
USER_LIBRARY-ESP32-S3-SOC_11
USER_LIBRARY-ESP32-S3-SOC_12
USER_LIBRARY-ESP32-S3-SOC_13
USER_LIBRARY-ESP32-S3-SOC_14
EXTRUDED-619032
EXTRUDED-619427
EXTRUDED-619822
_2_1_2_3_4_AF0 x 2
_7_1_2_AF0 x 2
EXTRUDED-668274
EXTRUDED-668792
EXTRUDED-669476
SWITCH-TS24CA x 3
SMTSO-M2_5-4ET x 4
PITCH1MM-12PIN-SMT-HORIZONTAL
PITCH1MM-4PIN-SMT-HORIZONTAL x 2
HP1_25MM-2P-SMT-HORIZONTAL
PITCH1MM-2PIN-SMT-HORIZONTAL
HP1_25MM-4P-SMT-HORIZONTAL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

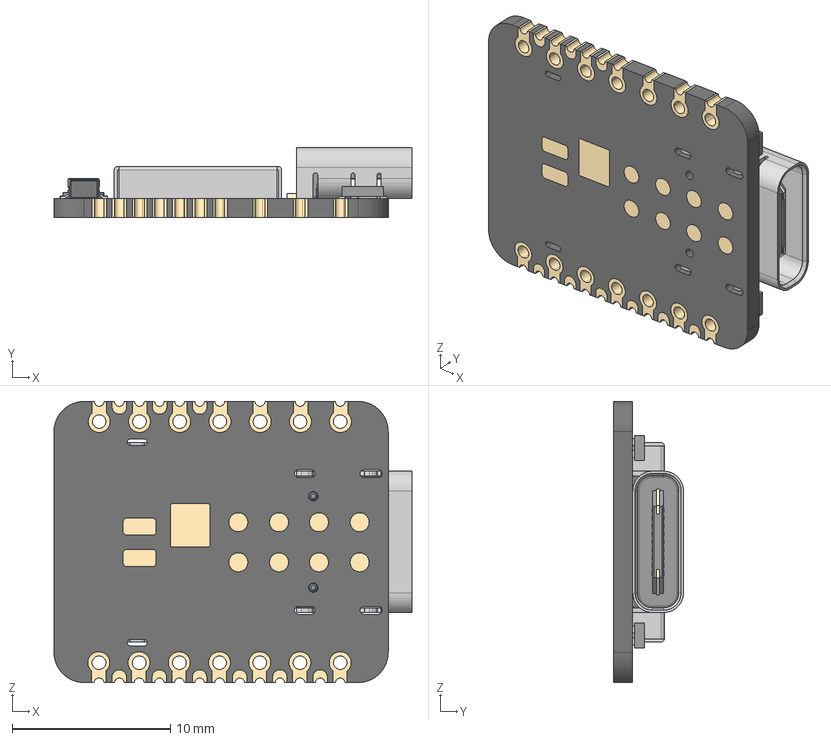
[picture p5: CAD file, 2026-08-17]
Hardware/PCB Components/Seeed Studio XIAO ESP32S3 Plus/XIAO ESP32S3 PLUS_.step
22.6 x 4.42 x 17.8 mm
DF40C-30DP-0.4V_51_ v1
BOSS-EXTRUDE14_8_
BOSS-EXTRUDE7_4_
BOSS-EXTRUDE7_3_
BOSS-EXTRUDE14_4_
BOSS-EXTRUDE14_2_
BOSS-EXTRUDE14_11_
BOSS-EXTRUDE7_7_
BOSS-EXTRUDE14_9_
BOSS-EXTRUDE14_3_
BOSS-EXTRUDE14_7_
MIRROR2
BOSS-EXTRUDE14_5_
BOSS-EXTRUDE14_12_
BOSS-EXTRUDE7_8_
BOSS-EXTRUDE7_1_
BOSS-EXTRUDE14_10_
BOSS-EXTRUDE7_9_
BOSS-EXTRUDE14_6_
BOSS-EXTRUDE14_1_
BOSS-EXTRUDE7_6_
BOSS-EXTRUDE7_2_
CUT-EXTRUDE5
BOSS-EXTRUDE7_5_
Shield
Pins x 2
U.FL-R-SMT-1_10_ v1

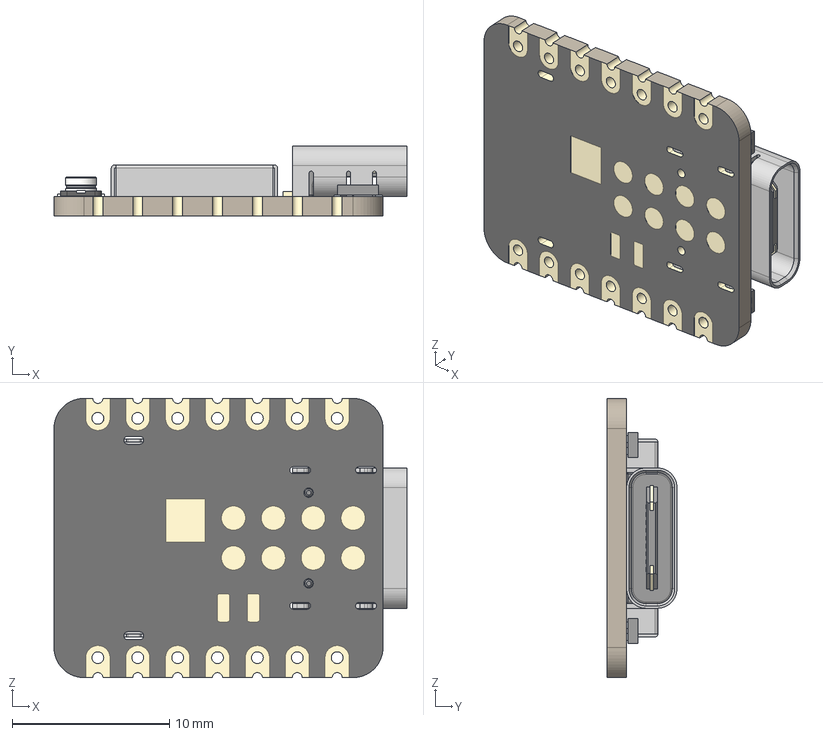
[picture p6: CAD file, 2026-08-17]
Hardware/PCB Components/Seeed Studio XIAO Series/XIAO-ESP32S3 v2.step
22.5 x 4.46 x 17.8 mm
BOSS-EXTRUDE14_8_
BOSS-EXTRUDE7_4_
BOSS-EXTRUDE7_3_
BOSS-EXTRUDE14_4_
BOSS-EXTRUDE14_2_
BOSS-EXTRUDE14_11_
BOSS-EXTRUDE7_7_
BOSS-EXTRUDE14_9_
BOSS-EXTRUDE14_3_
BOSS-EXTRUDE14_7_
MIRROR2
BOSS-EXTRUDE14_5_
BOSS-EXTRUDE14_12_
BOSS-EXTRUDE7_8_
BOSS-EXTRUDE7_1_
BOSS-EXTRUDE14_10_
BOSS-EXTRUDE7_9_
BOSS-EXTRUDE14_6_
BOSS-EXTRUDE14_1_
BOSS-EXTRUDE7_6_
BOSS-EXTRUDE7_2_
CUT-EXTRUDE5
BOSS-EXTRUDE7_5_
Shield
Pins x 2
U.FL-R-SMT-1_10_ v1

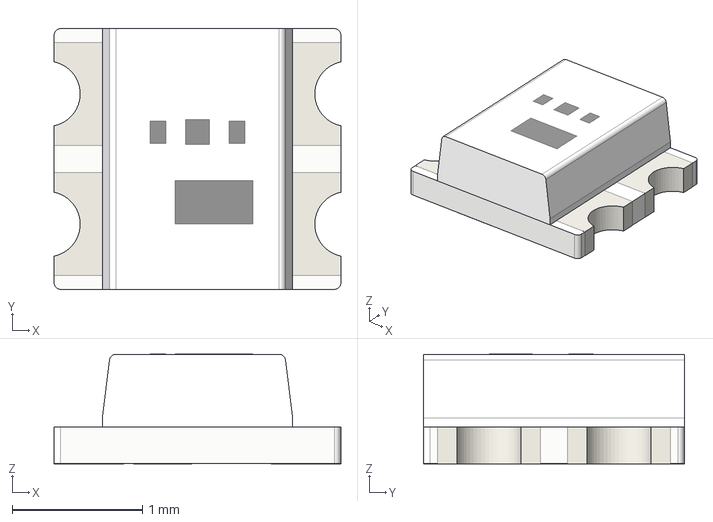
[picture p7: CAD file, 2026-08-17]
Hardware/PCB Components/WS2812B 2020/LED_WS2812_2020.step
2.20 x 2.00 x 0.842 mm

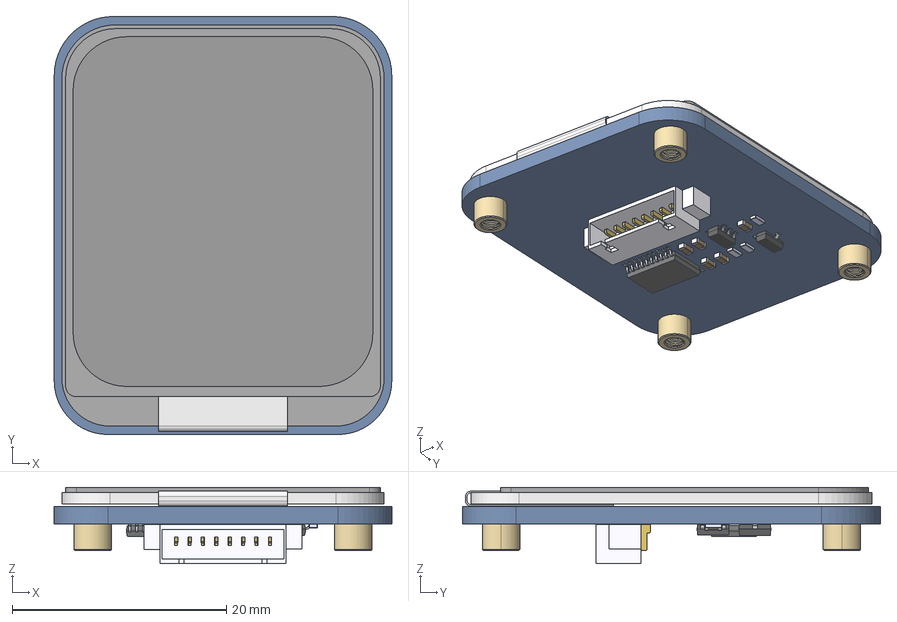
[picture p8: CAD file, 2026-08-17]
Hardware/PCB Components/1.69 inch LCD/1_69inch-lcd-module.stp
31.5 x 39.0 x 7.11 mm
1_69INCH-240X280-LCD
1_69INCH_LCD_MODULE-PCBA
STUDS-M2XH2_5 x 4

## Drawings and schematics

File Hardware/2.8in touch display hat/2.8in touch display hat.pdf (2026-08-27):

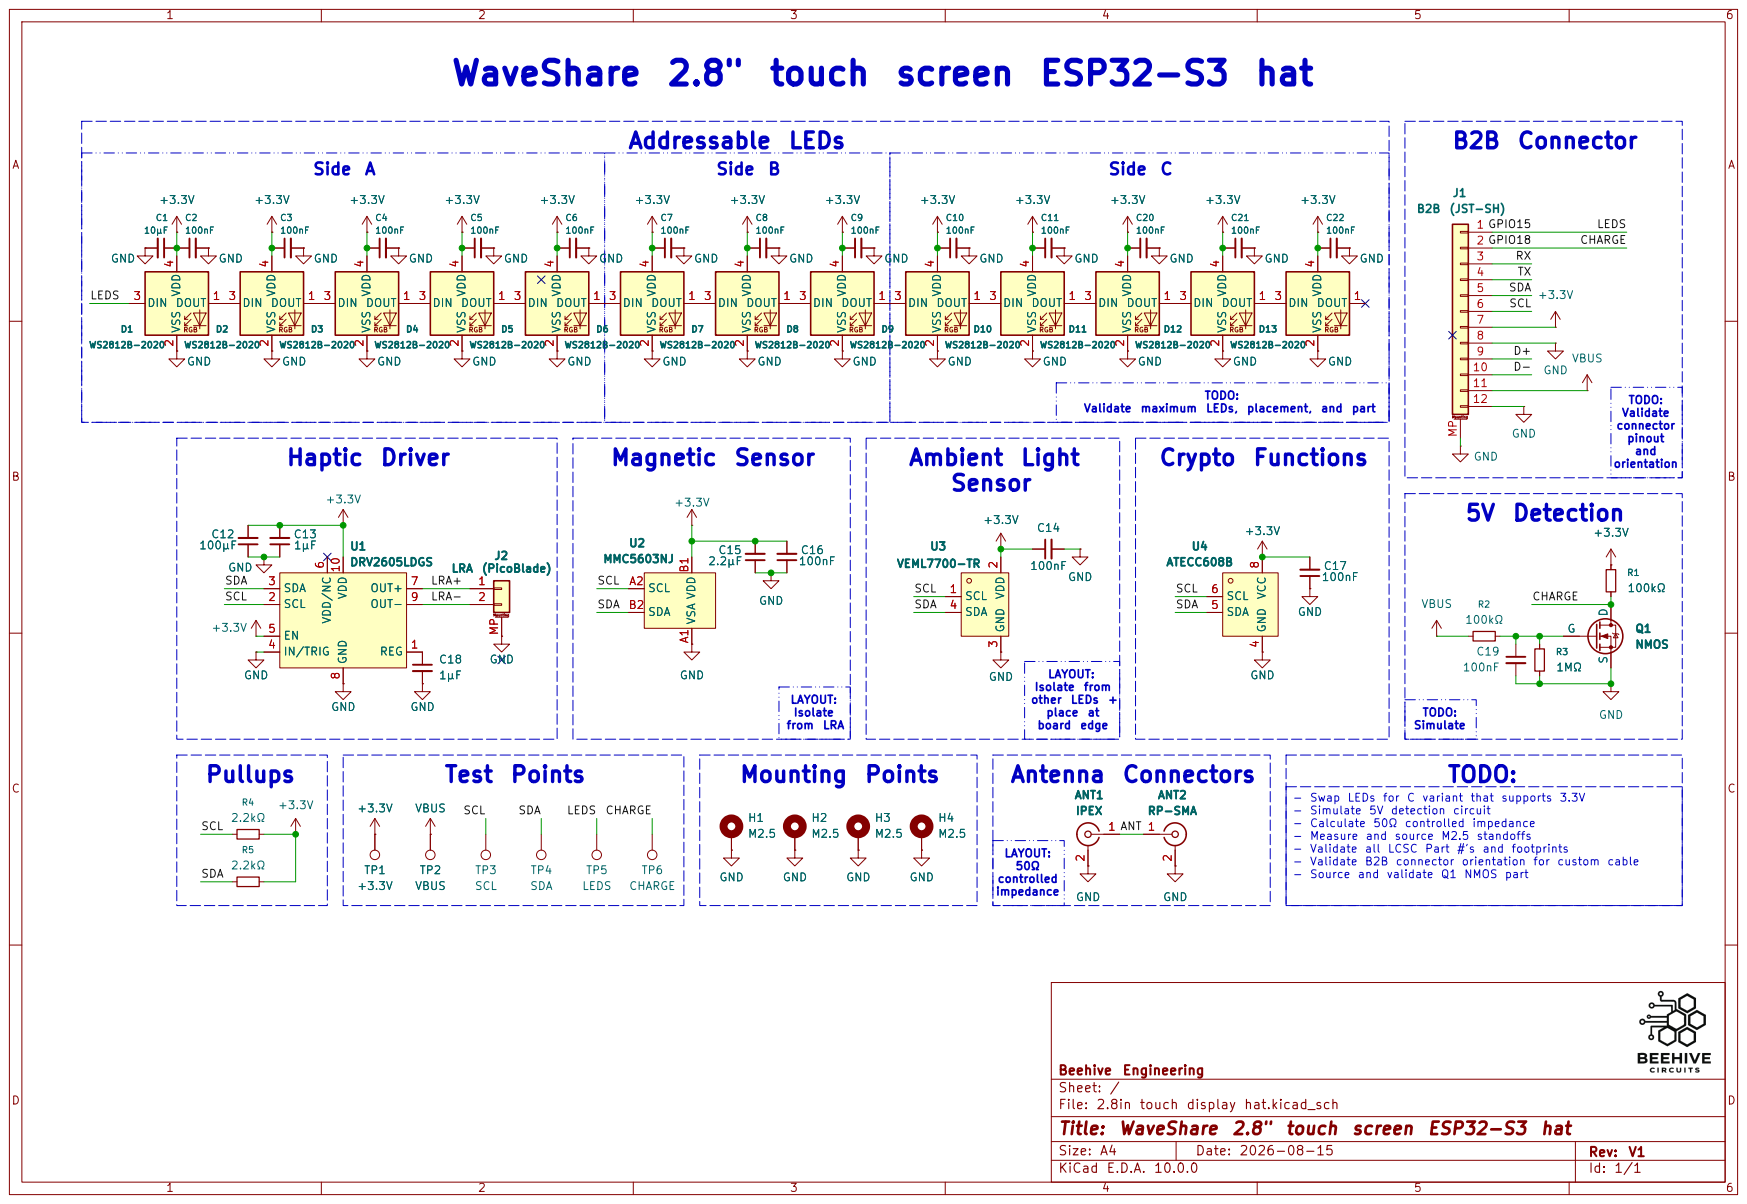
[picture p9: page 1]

TODO: Simulate WaveShare 2.8" touch screen ESP32-S3 hat

LAYOUT:
Isolate from
other LEDs +
place at board edge

Isolate
from LRA Mounting Points

TODO: - Swap LEDs for C variant that supports 3.3V - Simulate 5V detection circuit - Calculate 50Ω controlled impedance - Measure and source M2.5 standoffs - Validate all LCSC Part #'s and footprints - Validate B2B connector orientation for custom cable - Source and validate Q1 NMOS part

Beehive Engineering
Sheet: /
D Date: 2026-08-15 KiCad E.D.A. 10.0.0
File: 2.8in touch display hat.kicad_sch
Title: WaveShare 2.8" touch screen ESP32-S3 hat

Size: A4 | Rev: V1

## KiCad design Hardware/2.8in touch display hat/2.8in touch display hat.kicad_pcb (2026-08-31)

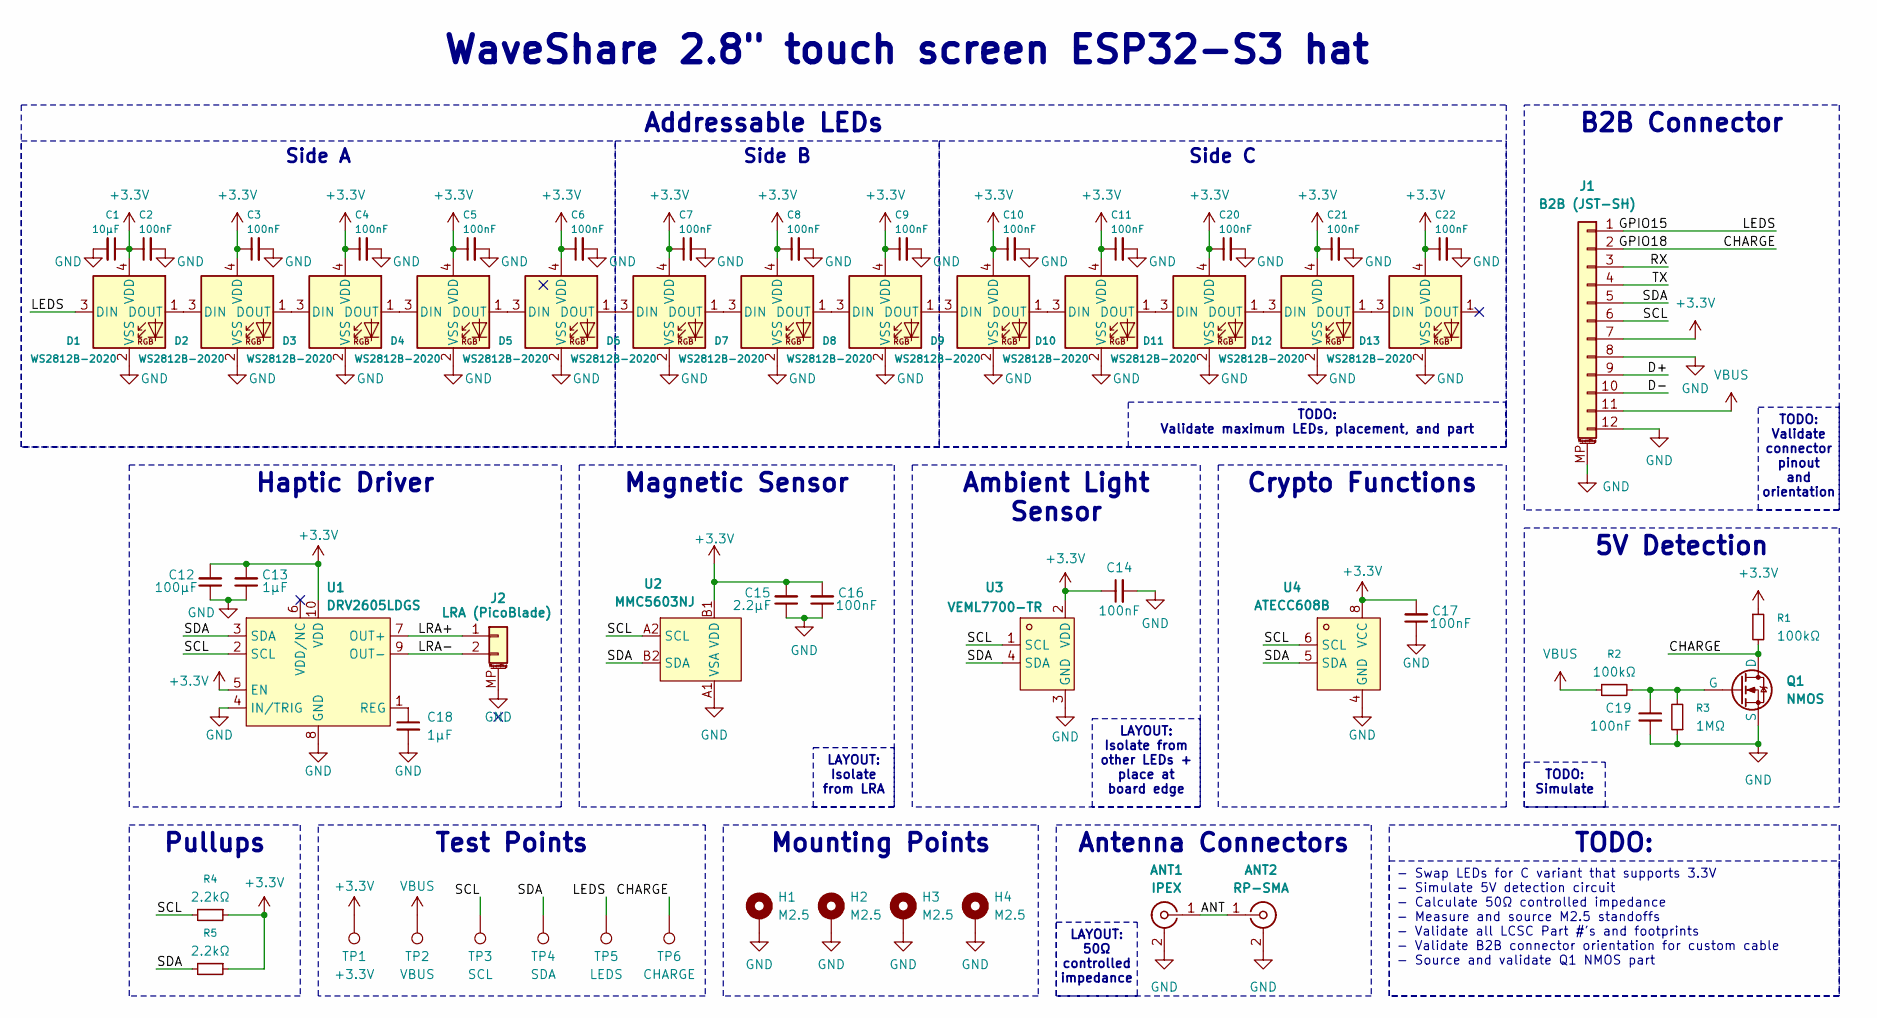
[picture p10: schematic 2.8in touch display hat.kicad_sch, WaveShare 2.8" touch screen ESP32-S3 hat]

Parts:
ANT1: IPEX; U.FL_Molex_MCRF_73412-0110_Vertical
ANT2: RP-SMA; SMA_Amphenol_901-143_Horizontal
C1: 10μF; C_1206_3216Metric
C2, C3, C4, C5, C6, C7, C8, C9, C10, C11, C14, C16, C17, C19, C20, C21, C22: 100nF; C_0603_1608Metric
C12: 100μF; C_0603_1608Metric
C13, C18: 1μF; C_0603_1608Metric
C15: 2.2μF; C_0603_1608Metric
D1, D2, D3, D4, D5, D6, D7, D8, D9, D10, D11, D12, D13: WS2812B-2020; LED_WS2812B-2020_PLCC4_2.0x2.0mm
H1, H2, H3, H4: M2.5; Mounting_Wuerth_WA-SMSI-M2.5_H1.5mm_9774015151
J1: B2B (JST-SH); JST_SH_SM12B-SRSS-TB_1x12-1MP_P1.00mm_Horizontal
J2: LRA (PicoBlade); Molex_PicoBlade_53261-0271_1x02-1MP_P1.25mm_Horizontal
Q1: NMOS; SOT-23-3
R1, R2: 100kΩ; R_0603_1608Metric
R3: 1MΩ; R_0603_1608Metric
R4, R5: 2.2kΩ; R_0603_1608Metric
TP1: +3.3V; TestPoint_Pad_D1.0mm
TP2: VBUS; TestPoint_Pad_D1.0mm
TP3: SCL; TestPoint_Pad_D1.0mm
TP4: SDA; TestPoint_Pad_D1.0mm
TP5: LEDS; TestPoint_Pad_D1.0mm
TP6: CHARGE; TestPoint_Pad_D1.0mm
U1: DRV2605LDGS; TSSOP-10_3x3mm_P0.5mm; LCSC Part # C504893
U2: MMC5603NJ; FLIPCHIP-4_L0.8-W0.8-R2-C2-P0.40-TL; MPN MMC5603NJ; LCSC Part C404328
U3: VEML7700-TR; LED-SMD_4P-L6.8-W2.4_VEML7700-TR; MPN VEML7700-TR; LCSC Part C504893
U4: ATECC608B; SOIC-8-1EP_3.9x4.9mm_P1.27mm_EP2.29x3mm; MPN ATECC608B-SSHDA-T; LCSC Part C1518769

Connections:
+3.3V: C1.1, C2.1, C3.1, C4.1, C5.1, C6.1, C7.1, C8.1, C9.1, C10.1, C11.1, C12.2, C13.2, C14.1, C15.2, C16.2, C17.2, C20.1, C21.1, C22.1, D1.4 (VDD), D2.4 (VDD), D3.4 (VDD), D4.4 (VDD), D5.4 (VDD), D6.4 (VDD), D7.4 (VDD), D8.4 (VDD), D9.4 (VDD), D10.4 (VDD), D11.4 (VDD), D12.4 (VDD), D13.4 (VDD), J1.7, R1.1, R4.1, R5.1, TP1.1 (1_1), U1.5 (EN), U1.10 (VDD), U2.B1 (VDD), U3.2 (VDD), U4.8 (VCC)
/ANT: ANT1.1 (In), ANT2.1 (In)
/CHARGE: J1.2, Q1.1 (D), R1.2, TP6.1 (1_1)
/D+: J1.9
/D-: J1.10
/GPIO15: D1.3 (DIN), J1.1, TP5.1 (1_1)
/LRA+: J2.1, U1.7 (OUT+)
/LRA-: J2.2, U1.9 (OUT-)
/RX: J1.3
/SCL: J1.6, R4.2, TP3.1 (1_1), U1.2 (SCL), U2.A2 (SCL), U3.1 (SCL), U4.6 (SCL)
/SDA: J1.5, R5.2, TP4.1 (1_1), U1.3 (SDA), U2.B2 (SDA), U3.4 (SDA), U4.5 (SDA)
/TX: J1.4
GND: ANT1.2 (Ext), ANT2.2 (Ext), C1.2, C2.2, C3.2, C4.2, C5.2, C6.2, C7.2, C8.2, C9.2, C10.2, C11.2, C12.1, C13.1, C14.2, C15.1, C16.1, C17.1, C18.2, C19.2, C20.2, C21.2, C22.2, D1.2 (VSS), D2.2 (VSS), D3.2 (VSS), D4.2 (VSS), D5.2 (VSS), D6.2 (VSS), D7.2 (VSS), D8.2 (VSS), D9.2 (VSS), D10.2 (VSS), D11.2 (VSS), D12.2 (VSS), D13.2 (VSS), H1.1 (1_1), H2.1 (1_1), H3.1 (1_1), H4.1 (1_1), J1.8, J1.12, J1.MP (MountPin), J2.MP (MountPin), Q1.3 (S), R3.1, U1.4 (IN/TRIG), U1.8 (GND), U2.A1 (VSA), U3.3 (GND), U4.4 (GND)
unnamed: D1.1 (DOUT), D2.3 (DIN)
unnamed: D2.1 (DOUT), D3.3 (DIN)
unnamed: D3.1 (DOUT), D4.3 (DIN)
unnamed: D4.1 (DOUT), D5.3 (DIN)
unnamed: D5.1 (DOUT), D6.3 (DIN)
unnamed: D6.1 (DOUT), D7.3 (DIN)
unnamed: D7.1 (DOUT), D8.3 (DIN)
unnamed: D8.1 (DOUT), D9.3 (DIN)
unnamed: D9.1 (DOUT), D10.3 (DIN)
unnamed: D10.1 (DOUT), D11.3 (DIN)
unnamed: D11.1 (DOUT), D12.3 (DIN)
unnamed: D12.1 (DOUT), D13.3 (DIN)
unnamed: C19.1, Q1.2 (G), R2.2, R3.2
unnamed: C18.1, U1.1 (REG)
VBUS: J1.11, R2.1, TP2.1 (1_1)

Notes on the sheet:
${TITLE}
Side B
Mounting Points
LAYOUT: Isolate from LRA
- Swap LEDs for C variant that supports 3.3V - Simulate 5V detection circuit - Calculate 50Ω controlled impedance - Measure and source M2.5 standoffs - Validate all LCSC Part #'s and footprints - Validate B2B connector orientation for custom cable - Source and validate Q1 NMOS part
Side A
Test Points
TODO: Validate maximum LEDs, placement, and part
LAYOUT: Isolate from other LEDs + place at board edge
TODO: Validate connector pinout and orientation
Magnetic Sensor
Ambient Light Sensor
Antenna Connectors
Pullups
B2B Connector
Side C
5V Detection
Addressable LEDs
LAYOUT: 50Ω controlled impedance
Crypto Functions
TODO: Simulate
TODO:
Haptic Driver

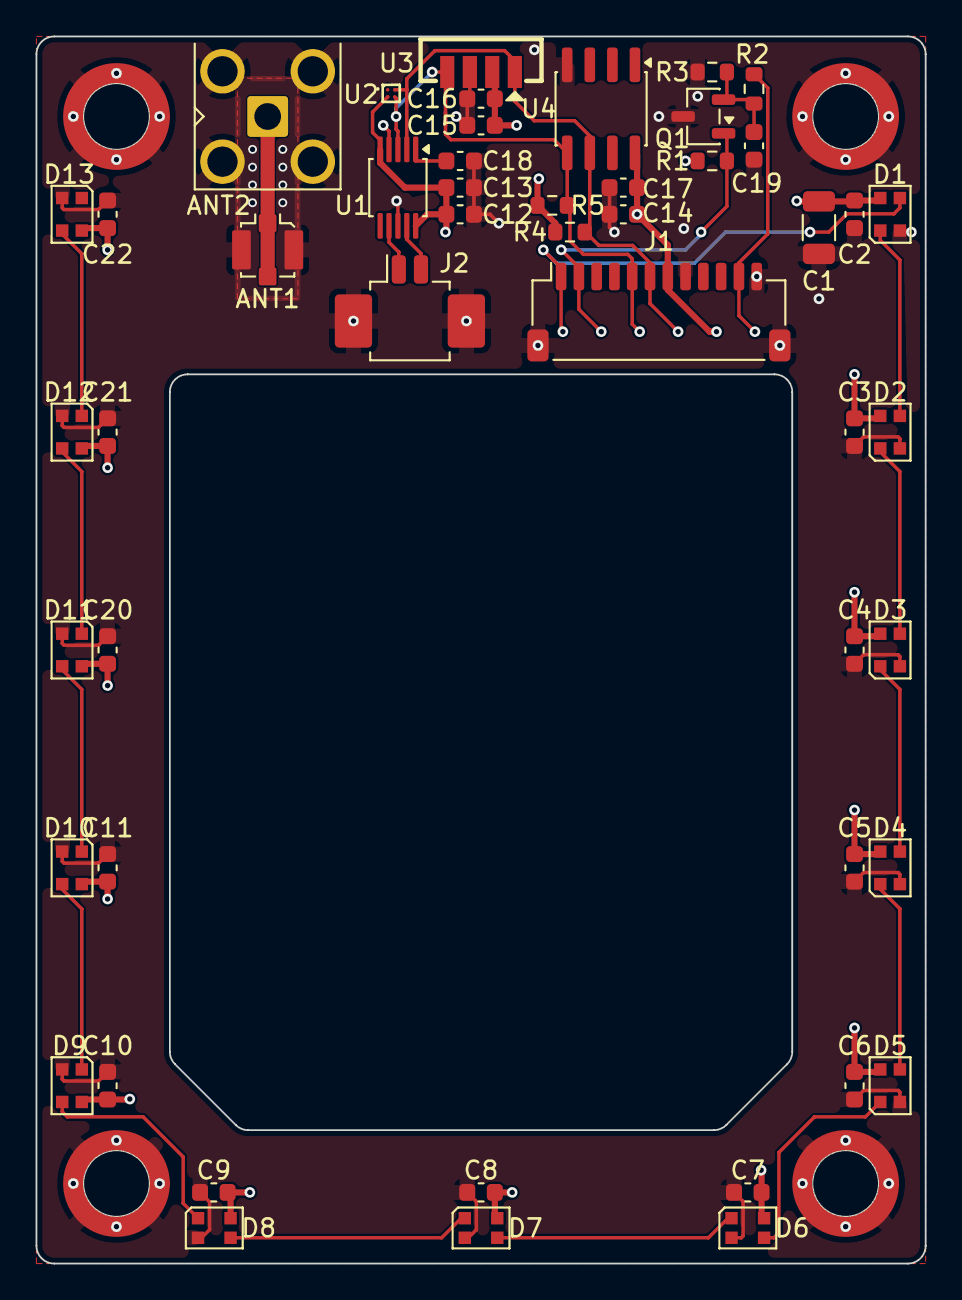
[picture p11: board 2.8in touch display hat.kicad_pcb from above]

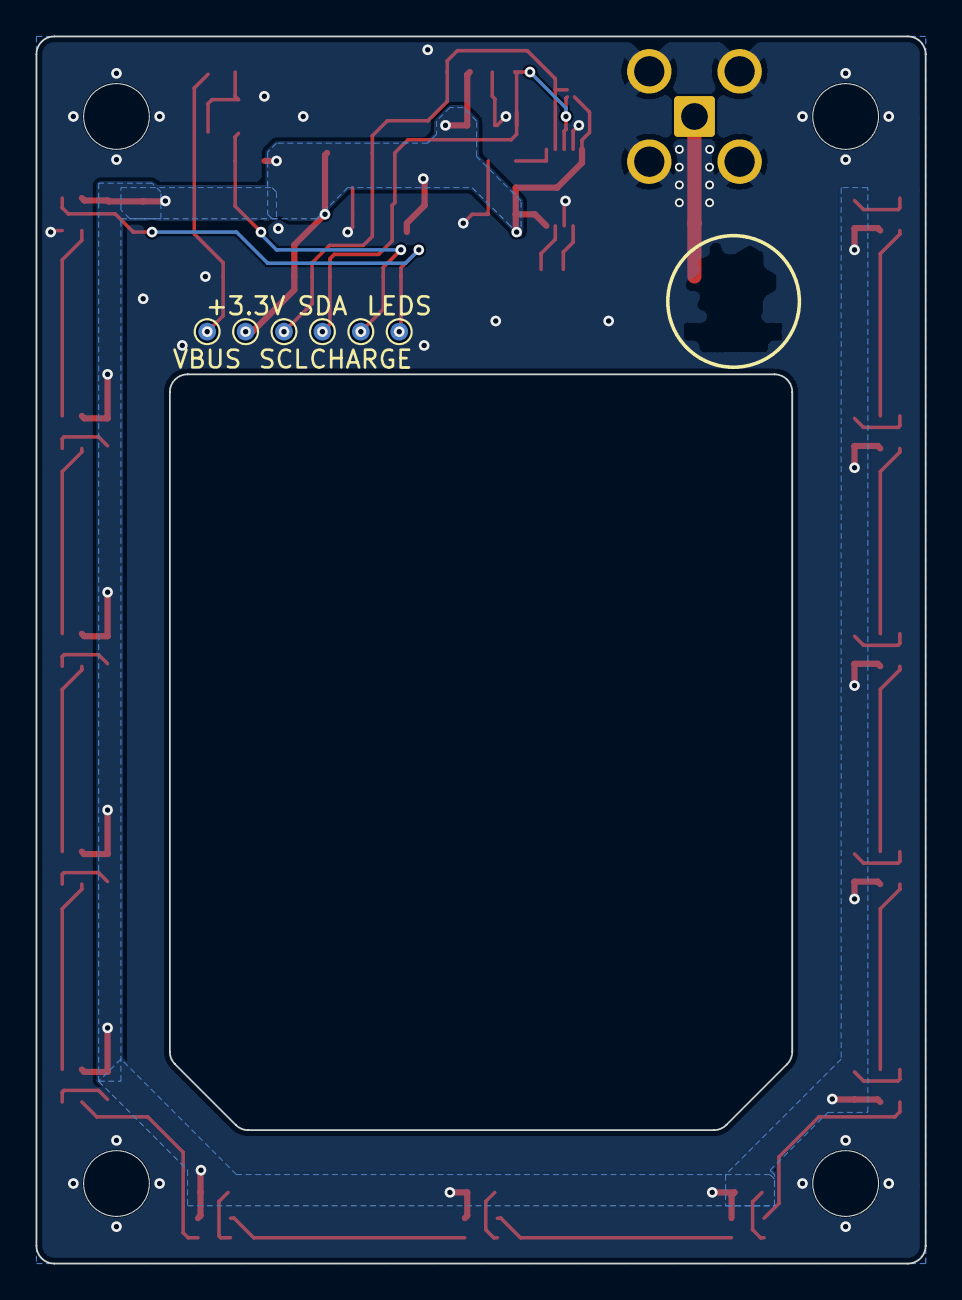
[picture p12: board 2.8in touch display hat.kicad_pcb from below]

Board: 2 copper layers, 50.0 x 69.0 mm, 59 parts (6 on the bottom side), 24 nets.

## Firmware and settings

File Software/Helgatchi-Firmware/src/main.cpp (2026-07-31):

#include <Arduino.h>
#include "event_bus.h"
#include "settings_service.h"
#include "hal.h"
#include "log_service.h"
#include "serial_console.h"
#include "power_manager.h"
#include "display_service.h"
#include "settings_screen.h"
#include "alerts_screen.h"
#include "devices_screen.h"
#include "foxhunting_screen.h"
#include "debug_screen.h"
#include "rules_screen.h"
#include "overview_screen.h"
#include "power_menu_screen.h"
#include "party_service.h"
#include "admin_service.h"
#include "ui_controller.h"
#include "led_service.h"
#include "vibe_service.h"
#include "alerts_service.h"
#include "scan_service.h"
#include "scan_engine.h"
#include "rules_service.h"
#include "perf_stats.h"
#include <LittleFS.h>
#include <esp_sleep.h>
#include <esp_system.h>

LoopPerf g_loop_perf;

static void _printBootInfo() {
    Serial.printf("[boot] chip:  %s rev%u  cores:%u\n",
                  ESP.getChipModel(), ESP.getChipRevision(), ESP.getChipCores());
    uint64_t mac = ESP.getEfuseMac();
    Serial.printf("[boot] mac:   %02X:%02X:%02X:%02X:%02X:%02X\n",
                  (uint8_t)(mac >> 40), (uint8_t)(mac >> 32), (uint8_t)(mac >> 24),
                  (uint8_t)(mac >> 16), (uint8_t)(mac >>  8), (uint8_t)(mac));
    Serial.printf("[boot] heap:  %lu B free\n",  (unsigned long)ESP.getFreeHeap());
    Serial.printf("[boot] flash: %lu KB\n",       (unsigned long)(ESP.getFlashChipSize() / 1024));
    Serial.printf("[boot] scan:  mode=%u  perf=%u  scan_s=%u  sleep_s=%u\n",
                  g_settings.get(SKEY_SCAN_MODE),   g_settings.get(SKEY_PERF_MODE),
                  g_settings.get(SKEY_SCAN_DURATION_S), g_settings.get(SKEY_SLEEP_DURATION_S));
    Serial.printf("[boot] vsense: %u mV\n", g_hal.readVsenseMv());
    Serial.printf("[boot] debug: level=%u  sleep_w_serial=%u\n",
                  g_settings.get(SKEY_DEBUG_LEVEL),
                  g_settings.getBool(SKEY_DEBUG_SLEEP_WITH_SERIAL));
}

void setup() {
    Serial.begin(115200);

    // EARLIEST: on a button wake from deep sleep (regular or shipping), verify
    // the user is holding CENTER long enough — otherwise re-enter the same
    // sleep without spinning anything else up. May not return. Timer wakes and
    // cold boots pass straight through.
    PowerManager::checkWakeHoldOrResleep();

    // Read once here; the boot-indicator block below reuses it.
    const esp_sleep_wakeup_cause_t wake_cause = esp_sleep_get_wakeup_cause();

    // Wait for a USB CDC host to attach so the boot log isn't lost — but only
    // when someone could be watching. A TIMER wake is an autonomous scan cycle
    // running on battery with the screen off, where CDC never asserts, so this
    // burned its full 2 s at 240 MHz on EVERY cycle: more than a third of the
    // fixed per-cycle overhead, for a log nobody reads. Cold boot and button
    // wakes still wait, so flashing and interactive debugging are unchanged.
    if (wake_cause != ESP_SLEEP_WAKEUP_TIMER) {
        const uint32_t t0 = millis();
        while (!Serial && (millis() - t0) < 2000) { delay(10); }
        delay(200);
    }

    g_bus.begin();
    g_settings.begin(g_bus);
    g_hal.begin(g_bus);
    g_logger.begin(g_bus);
    g_console.begin(g_bus);
    g_power.begin(g_bus);
    g_alerts.begin(g_bus); // must precede led/vibe so they can find() records when EV_ALERT_RAISED fires
    g_scan_service.begin(g_bus);          // ring buffer + seen-devices map
    g_scan_engine.begin(g_bus);   // NimBLE driver — publishes into g_scan_service
    // LittleFS must be mounted before RulesService reads /rules/factory and
    // /rules/user. formatOnFail=true so a fresh device with no FS image
    // still boots (it'll just find an empty filesystem).
    if (!LittleFS.begin(true /* formatOnFail */)) {
        Serial.println("[fs] FATAL: LittleFS mount failed — rules subsystem disabled");
    }
    g_rules.begin(g_bus);  // must follow LittleFS mount + g_scan_service + g_alerts
    g_leds.begin(g_bus);   // depends on HAL (LED chain) + bus events from PowerManager
    g_vibe.begin(g_bus);   // haptic patterns; subscribes to button + alert events
    g_ui.begin(g_bus);     // creates the LVGL display — auto-shows perf overlay
    g_logger.attachLvglLog(); // route LVGL logs to serial (Render debug level) — must follow lv_init
    g_display.begin(g_bus); // top-bar indicators — must follow g_ui (objects.* must exist)
    g_settings_screen.begin(g_bus); // settings widget wiring — must follow g_ui
    g_alerts_screen.begin(g_bus);   // alert cards UI — must follow g_ui + g_display + g_alerts
    g_devices_screen.begin(g_bus);  // device cards UI — must follow g_ui + g_scan_service
    g_foxhunting_screen.begin(g_bus); // foxhunt lock-on UI — must follow g_ui + g_scan_service + g_scan_engine
    g_debug_screen.begin(g_bus);    // diagnostics view — must follow g_ui
    g_rules_screen.begin(g_bus);    // rule cards UI — must follow g_ui + g_rules
    g_overview_screen.begin(g_bus); // Helga character animation — must follow g_ui
    g_party.begin(g_bus);           // party mode — must follow g_ui + g_overview_screen (references objects.*)
    g_admin.begin(g_bus);           // admin mode — must follow g_scan_engine (BLE init + admin queue) + g_ui (objects.*)
    g_power_menu_screen.begin(g_bus); // power menu buttons + sleep countdown — must follow g_ui
    g_logger.applyPerfMonitor();   // re-hide unless level >= RENDERING_PERF

    if (g_settings.getBool(SKEY_DEBUG_SERIAL_ENABLED)) {
        _printBootInfo();
    }

    // Boot indicator: white LED flash + short haptic. Only fires for boots
    // the user *initiated* — fresh power-on, or button wake from deep sleep.
    // Software resets (Reboot button calling ESP.restart, panic, watchdog)
    // get NO indicator: the user just produced a haptic clicking the button
    // that triggered the reset, and a second haptic on the other side feels
    // like one long buzz. TIMER wakes (autonomous scan) also stay silent.
    {
        esp_reset_reason_t       reset  = esp_reset_reason();
        bool show_indicator =
            (reset == ESP_RST_POWERON) ||
            (reset == ESP_RST_DEEPSLEEP && wake_cause == ESP_SLEEP_WAKEUP_EXT1);

        if (show_indicator) {
            g_hal.setAllLEDs(30, 30, 30);
            if (g_settings.getBool(SKEY_ALERT_VIBRATION)) {
                g_hal.setVibrate(220);
                delay(60);
                g_hal.stopVibrate();
                delay(140);
            } else {
                delay(200);
            }
            g_hal.clearLEDs();
        }
    }

    Serial.println("[Helgatchi] boot OK");
}

void loop() {
    // Per-phase timing folded into g_loop_perf (worst tick per 1 s window). One
    // micros() read per phase — negligible — so it runs unconditionally;
    // LogService reports it only at DEBUG_PERF. See perf_stats.h.
    uint32_t _t = micros();
    const uint32_t _loop_start = _t;

    PERF_TIME(hal_us,     g_hal.tick());         // USB SOF (attach) detection — buttons + haptics run on their own esp_timers
    PERF_TIME(bus_us,     g_bus.dispatch());     // drain event queue and call all handlers (device-list rebuild runs here)
    PERF_TIME(console_us, g_console.tick());     // process any pending serial input
    PERF_TIME(power_us,   g_power.tick());       // scan/sleep cycle + battery sampling
    PERF_TIME(scan_us,    g_scan_engine.tick()); // drain NimBLE callback queue + publish to g_scan_service
    g_admin.tick();                              // drain + auth admin command frames; expire admin effects
    PERF_TIME(rules_us,   g_rules.tick());       // drain scan ring + match against loaded rules
    PERF_TIME(leds_us,    g_leds.tick());        // ~30 FPS LED pattern render (frame-skips internally)
    g_party.tick();                              // party mode: re-fire haptics, cycle banner colour, keep-awake (no-op when idle)
    PERF_TIME(ui_us,      g_ui.tick());          // lv_timer_handler — drives LVGL rendering
    // Haptics no longer tick here — VibeService runs its step machine on a
    // one-shot esp_timer, immune to loop-cadence stalls (see vibe_service.h).

    const uint32_t _loop_dt = micros() - _loop_start;
    if (_loop_dt > g_loop_perf.loop_us) g_loop_perf.loop_us = _loop_dt;
    g_loop_perf.iterations++;
}

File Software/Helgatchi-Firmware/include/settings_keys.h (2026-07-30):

#pragma once
#include <stdint.h>

// ---------------------------------------------------------------------------
// Supporting enums
// ---------------------------------------------------------------------------

enum PerfMode : uint8_t {
    PERF_PERFORMANCE = 0,  // near-continuous scan, long wake duration
    PERF_BALANCED,         // moderate duty cycle, default timeouts
    PERF_BATTERY_SAVER,    // long intervals, short windows, aggressive sleep
    PERF_DYNAMIC,          // runtime auto-adjustment based on battery level
    PERF_ALWAYS_ON,        // while charging: never sleeps, screen stays on, ~0 gap
                           // between scan windows. On battery: normal duty cycle
                           // (this mode is meant for external power).
    PERF_MODE_COUNT
};

enum ScanMode : uint8_t {
    SCAN_DISABLED = 0,
    SCAN_BLE_ONLY,
    SCAN_WIFI_ONLY,
    SCAN_BLE_AND_WIFI,
    SCAN_MODE_COUNT
};

enum ScreenBrightness : uint8_t {
    SCREEN_BRIGHTNESS_MIN = 0,    // dim but still legible — floor for the user
    SCREEN_BRIGHTNESS_LOW,
    SCREEN_BRIGHTNESS_MEDIUM,
    SCREEN_BRIGHTNESS_HIGH,
    SCREEN_BRIGHTNESS_MAX,
    SCREEN_BRIGHTNESS_COUNT
};

enum LEDBrightness : uint8_t {
    LED_BRIGHTNESS_LOW = 0,
    LED_BRIGHTNESS_MEDIUM,
    LED_BRIGHTNESS_HIGH,
    LED_BRIGHTNESS_MAX,
    LED_BRIGHTNESS_COUNT
};

enum DebugLevel : uint8_t {
    DEBUG_INFORMATIONAL = 0,
    DEBUG_HIGH,
    DEBUG_RENDERING_PERF,
    DEBUG_SCANNING_PERF,
    DEBUG_PERF,             // periodic (1 s) memory + scan-pressure + loop-timing telemetry (human-readable)
    DEBUG_TELEPLOT,         // periodic (1 s) Teleplot ">k:v" stream for live graphing
    DEBUG_LEVEL_COUNT
};

// ---------------------------------------------------------------------------
// Settings keys
//
// [USER]    — shown on Settings screen, user can change
// [DEBUG]   — row hidden unless SKEY_DEBUG_ENABLED is on; reset to default
//             when that toggle is switched off
// [DERIVED] — set automatically (by perf mode, build flags, or linked setting)
//             not shown in UI
//
// NOTE: The following debug items are ACTIONS, not stored settings.
//       They emit commands — see event_ids.h:
//         "Reset statistics"          → CMD_STATS_RESET
//         "Reset settings"            → CMD_SETTINGS_RESET_DEFAULTS
//         "Reset device" (wipe+reboot)→ CMD_POWER_FACTORY_RESET
//         wipe+ship (serial only)     → CMD_POWER_SHIPPING_RESET
// ---------------------------------------------------------------------------

enum SettingsKey : uint8_t {

    // --- Display ---
    SKEY_SCREEN_BRIGHTNESS = 0,     // [USER]    ScreenBrightness
    SKEY_LED_BRIGHTNESS,            // [USER]    LEDBrightness

    // --- Scanning ---
    SKEY_SCAN_MODE,                 // [USER]    ScanMode
    SKEY_SCAN_ACTIVE,               // [USER]    bool — active scan (solicit scan responses) vs passive
    SKEY_PERF_MODE,                 // [USER]    PerfMode

    // --- Alerts ---
    SKEY_ALERT_WAKE_SCREEN,         // [USER]    bool — alert wakes display
    SKEY_ALERT_VIBRATION,           // [USER]    bool
    SKEY_ALERT_LED,                 // [USER]    bool
    SKEY_ALERT_FOCUS,               // [USER]    bool — alert loads the Alerts screen (except while on Settings)

    // --- Power ---
    SKEY_SLEEP_WHILE_USB,           // [USER]    bool — allow sleep when USB attached (no serial)
    SKEY_VSENSE_5V_DIVIDER,         // [USER]    bool — HW has R4 (+5V→VSENSE) populated; changes VBATT math

    // --- Debug (rows gated by SKEY_DEBUG_ENABLED) ---
    SKEY_DEBUG_SERIAL_ENABLED,      // [DEBUG]   bool — USB serial debug output
    SKEY_DEBUG_LEVEL,               // [DEBUG]   DebugLevel
    // Enum name keeps its DEBUG_ prefix (NVS slot is positional), but this is
    // a plain sleep-while behavior flag now, shown with SLEEP_WHILE_USB /
    // SLEEP_WHILE_CHARGING — not gated, not reset by the debug toggle.
    SKEY_DEBUG_SLEEP_WITH_SERIAL,   // [USER]    bool — allow sleep even when serial connected

    // Occupies the slot vacated by the removed [DERIVED] SKEY_SCREEN_TIMEOUT_S
    // (which was dead — nothing consumed it). Kept in place rather than appended;
    // SCHEMA_VERSION is bumped so the old value in this slot resets to default
    // instead of being misread as this bool.
    SKEY_SLEEP_WHILE_CHARGING,      // [USER]    bool — allow sleep while charging (default off = inhibit; peer to SLEEP_WHILE_USB / DEBUG_SLEEP_WITH_SERIAL)

    // --- Internal / derived (not shown in UI) ---
    SKEY_INTERACTIVE_TIMEOUT_S,     // [DERIVED] seconds of inactivity before sleep (resets on EV_UI_ACTIVITY)
    SKEY_SLEEP_DURATION_S,          // [DERIVED] seconds the device sleeps between scan cycles
    SKEY_SCAN_DURATION_S,           // [DERIVED] seconds to scan per wake cycle; tuned by perf mode

    SKEY_TUTORIAL_SHOWN,            // [INTERNAL] bool — cleared on first flash / shipping wake
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

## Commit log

2026-07-16 Update Helgatchi UI.eez-project
    Add 43 new frames of Helga animations
2026-07-16 Update Helgatchi UI.eez-project
    Add frames to AnimationImage
2026-07-16 Update Helgatchi UI.eez-project
    Adding two additional frames for a simpler backwards animation.
2026-07-16 Update overview_screen.cpp
    Index frames and label animations for Helga
2026-07-21 Update battery capacity range in README
2026-07-22 Add rule toggling page and logic
    [motorola_solutions.json]
2026-07-23 LED fixes
2026-07-23 Update settings menu + new wipe/reset/ship commands
    [log_service.cpp, power_manager.cpp, power_manager.h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]
2026-07-23 add power action menu
2026-07-23 fix battery voltage and charge state detecion
    [hal.cpp, power_manager.cpp, power_manager.h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]
2026-07-23 Fix LED timing
2026-07-24 shippoing mode button in web flasher
2026-07-24 Power manager updates for sleep mode
2026-07-24 add shipping mode button
2026-07-24 feat: add tag field to factory rules and update documentation
    [motorola_solutions.json]
2026-07-24 feat: add factory detection rules for multiple wearable and covert camera devices
2026-07-24 feat: add factory rule definitions for smart home devices and some audio devices.
2026-07-24 feat: update factory rule tags to title case and removed special characters. This is a user visable field and needs to be prettified.
2026-07-24 refactor: update factory rules for names, viberations, and led.
    [motorola_solutions.json]
2026-07-24 feat: add factory device detection rules for tracker devices
2026-07-24 feat: add new factory rules for device detection for audio devices and removed hidden cam tag
2026-07-25 Expose beacon vs probe data in devices page
2026-07-25 New rulesets for detection
    [motorola_solutions.json]
2026-07-25 update tags
    [motorola_solutions.json]
2026-07-26 Fix screen wake button passthrough
    [hal.cpp, hal.h, log_service.cpp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]
2026-07-26 fix service ID scan engine
    [rules_service.cpp, serial_console.cpp]
2026-07-26 adjust device details
2026-07-26 add buy button to webflasher
2026-07-30 View alerting device details
2026-07-30 speed up always-on scan swapping
    [settings_keys.h]
2026-07-31 Skip the USB CDC wait on timer wakes
    setup() waited up to 2 s for a CDC host to attach so the boot log isn't
    lost, then settled another 200 ms. Deep sleep resets the chip, so this ran
    on every autonomous scan cycle — on battery, where CDC never asserts, with
    the screen off and nobody reading the log. That is ~2.2 s at 240 MHz of the
    ~3.4 s fixed overhead per cycle, against a 5 s scan window.
    Gate it on the wake cause: TIMER skips, POWERON and EXT1 still wait, so
    flashing and interactive debugging are unaffected. The cause is now read
    once at the top and reused by the boot-indicator block below.
    [main.cpp]
2026-07-31 Report rule-load timing at boot
    Rules load on every wake — deep sleep resets the chip, so a silent scan
    cycle reruns the whole thing — which makes it fixed per-cycle overhead.
    Nothing reported how long it took.
    begin() now prints a breakdown after the existing count line: total, mkdir,
    factory and user files/ms separately, NVS overlay, plus average and slowest
    single file. The slowest-file figure is the useful discriminator — uniform
    per-file cost points at LittleFS/JSON throughput, one outlier points at a
    specific rule.
    reloadFromFs() prints the same breakdown so `rules reload` re-times without
    a power cycle, though with a warm FS cache it will read faster than a
    cold-boot load.
    [rules_service.cpp]
2026-08-17 Initial Plus commit
    [1.69inch_LCD_Module_2Ddrawing.dxf, 1_69inch-lcd-module.stp, 2.8in touch display hat.kicad_pcb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]
2026-08-30 first pass routing
    [2.8in touch display hat.kicad_pcb, backup.2.8in touch display hat.kicad_pcb, backup.2.8in touch display hat.kicad_sch]
2026-08-31 PCB R1.5
    [2.8in touch display hat.kicad_pcb, 2.8in touch display hat.kicad_sch, esp32-s3-touch-lcd-2_8.stp]
